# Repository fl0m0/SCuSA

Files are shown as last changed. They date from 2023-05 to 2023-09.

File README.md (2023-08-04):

# SCuSA
 **S**cope **Cu**rrent **S**ense **A**mplifier, work in progress

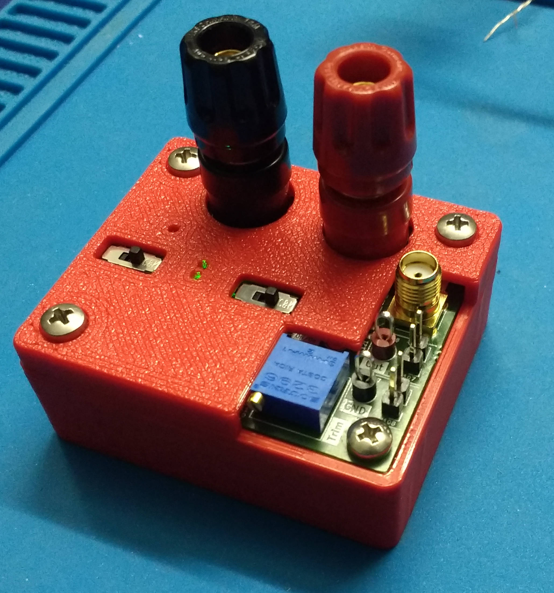
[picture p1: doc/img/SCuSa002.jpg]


# Design goals

The main reason I designed this current sense amplifier was the need to verify power supplys on PCBs:

* Turn on behavior
* Inrush current
* Short circuit current
* Ripple current

My main requirements were:

* High side measurement > 60 V
* Common mode input range down to 0 V
* Burden voltage below 150 mV
* No galvanic isolation
* Current range up to approx ~3 A
* Accuracy better than 2%
* Bandwith > 150 kHz
* Bonus: Measurement of negative current (for battery charging applications)

I had already built a simple current sense amplifier based on the [INA169](https://www.ti.com/product/INA169) on a breadboard. It fullfilled most of my requirements except the common mode voltage range: 2.7 V made it impossible to measure 1.8 V or 1.0 V voltage supplies which are quite common these days.

I ended up with a design way to complicated and expensive :-) But I really wanted to try out a few interesting ICs:

* [LM27762](https://www.ti.com/product/LM27762): "Low-Noise Positive and Negative Output Integrated Charge Pump Plus LDO"
* [AD8210A](https://www.analog.com/en/products/ad8210.html) or [AD8418A](https://www.analog.com/en/products/ad8418a.html): Very fancy looking "High Voltage, Bidirectional Current Shunt Monitors"

# Current status

* RevA built and partially tested
* Documentation not finished
* RevB work in progress (fixed errors, improvements)

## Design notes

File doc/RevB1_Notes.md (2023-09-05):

# Modifications

1. Change F1 to 0.75 A polyfuse SMD1206B075TF/16

2. Bodge wire to U111 charge pump VIN pin. Othervise the output voltage stayed at 1.6 V. This is due to an layout error: EN was mistaken with VIN. The resulting impedance of the long, narrow track to VIN was obviously to high (the switching frequency is 2 MHz!).

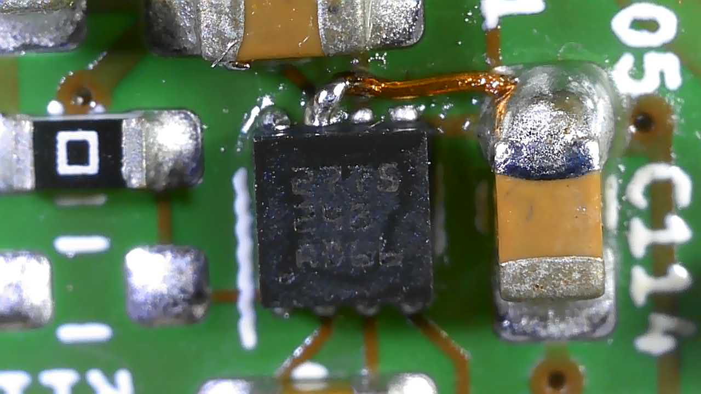
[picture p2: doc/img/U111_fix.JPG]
   

# Power supply

Current consumption is 20 mA. Iq of [LM2775](https://www.ti.com/lit/ds/symlink/lm2775.pdf?ts=1693816107344&ref_url=https%253A%252F%252Fwww.google.com%252F) is 5 mA typ. with forced PWM mode (PFM = 0). Doesn't vary with change of input voltage.

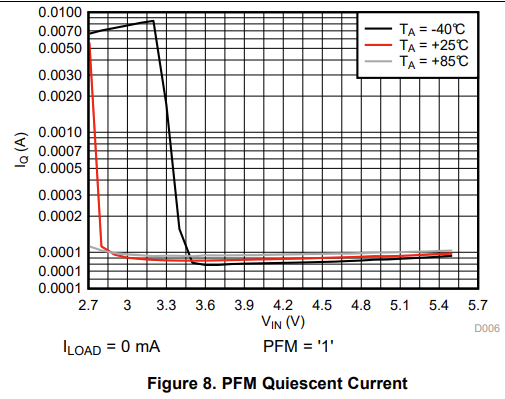
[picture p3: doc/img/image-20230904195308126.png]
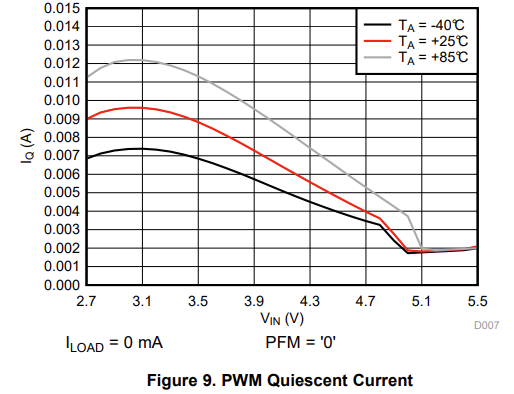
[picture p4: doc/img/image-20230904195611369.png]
 

In RevA1 current consumption was 7 mA with Vx- = GND (-2V unused but present). The "old" LM27762 had an Iq of 390 µA.

| Component | Quiescent Current (mA) |
| --- | --- |
| AD8418A | 4.1 |
| AD8655 | 3.7 |
| LM2775 | 5.0 |
| **Total** | **12.8** |

Efficency is around 45%:

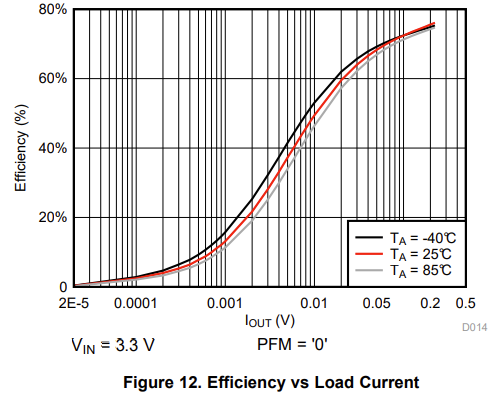
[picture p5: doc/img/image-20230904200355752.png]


$\frac{(4.1\ +\ 3.7)\ mA}{45\ \%}\ =\ 17.3\ mA$ so the measurements seem plausible. PFM mode shouldn't improve the results with load current > 7 mA:

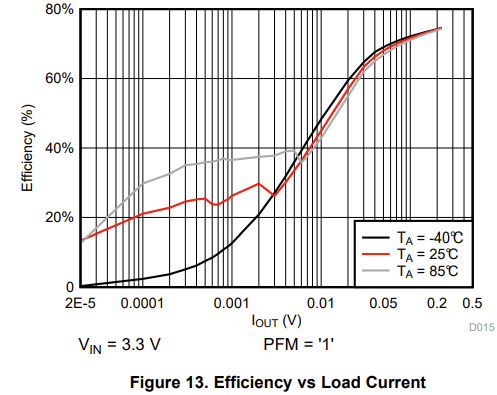
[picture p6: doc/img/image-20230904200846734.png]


## +5V voltage ripple

First screenshot before ferrite, second after ferrite. Filter reduces the ripple approx. 2.7 times.

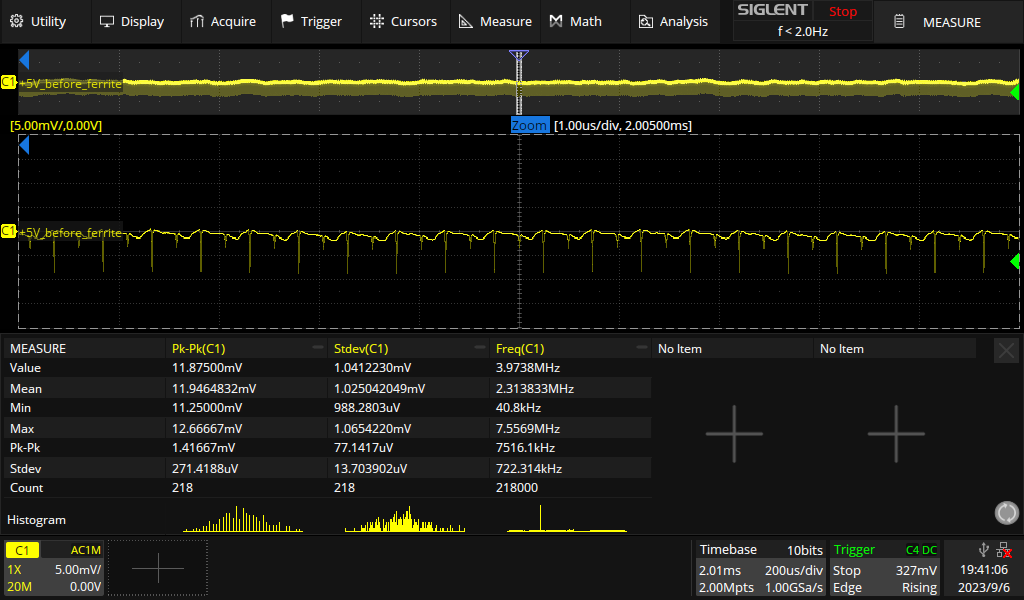
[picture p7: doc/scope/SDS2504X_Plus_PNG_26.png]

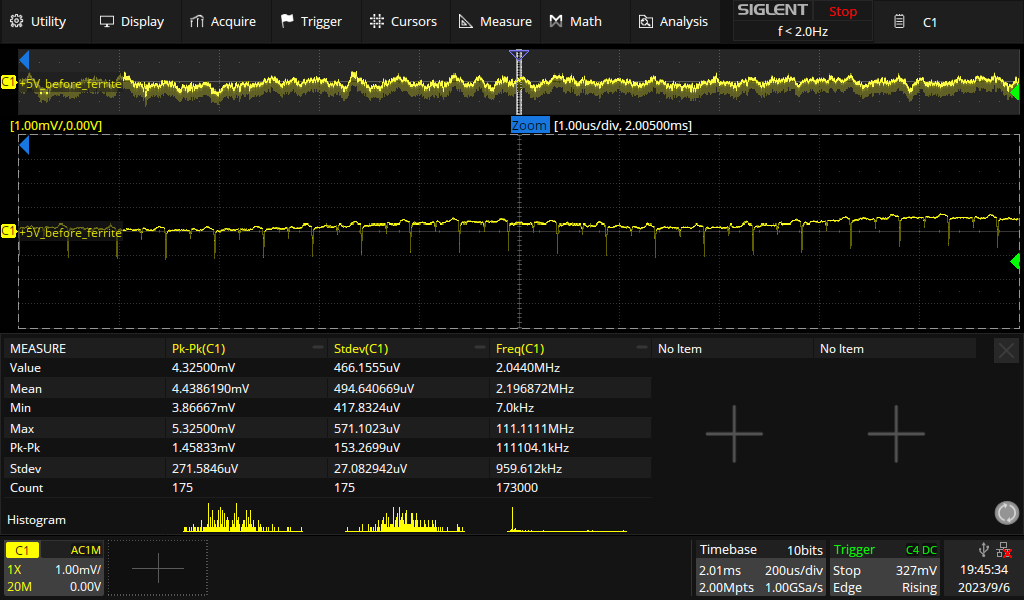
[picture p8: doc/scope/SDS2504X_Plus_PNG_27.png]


+5V after ferrite, bufferd output loaded with 50 Ohms. No significant increase in ripple voltage.

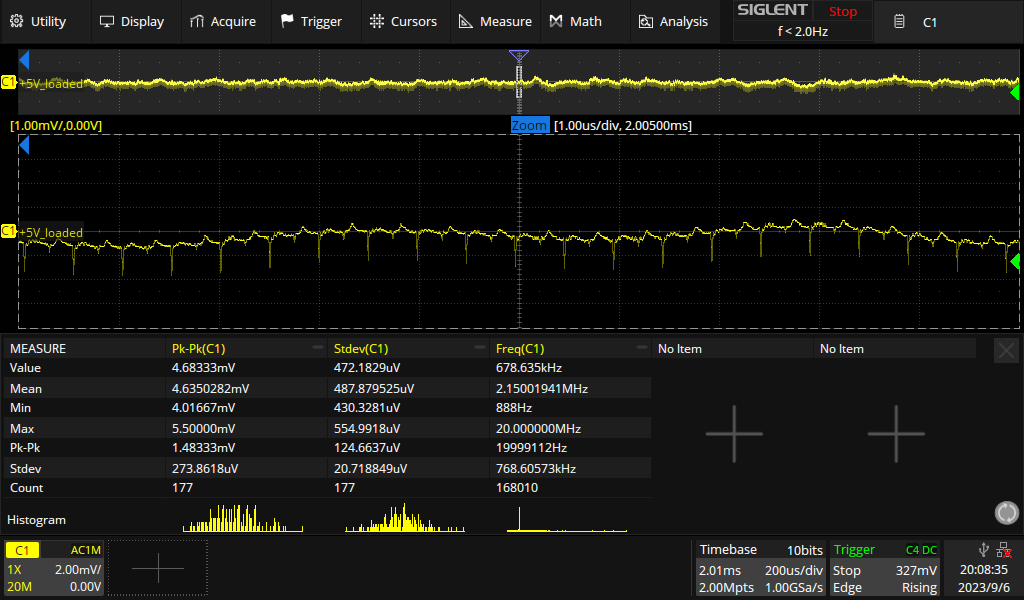
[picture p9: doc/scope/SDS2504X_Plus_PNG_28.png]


## Load regulation

See spreadsheet

# Output measurements

## Output voltage at 0 A

`Probe` = unbuffered output

`Koax` = 50R buffered output

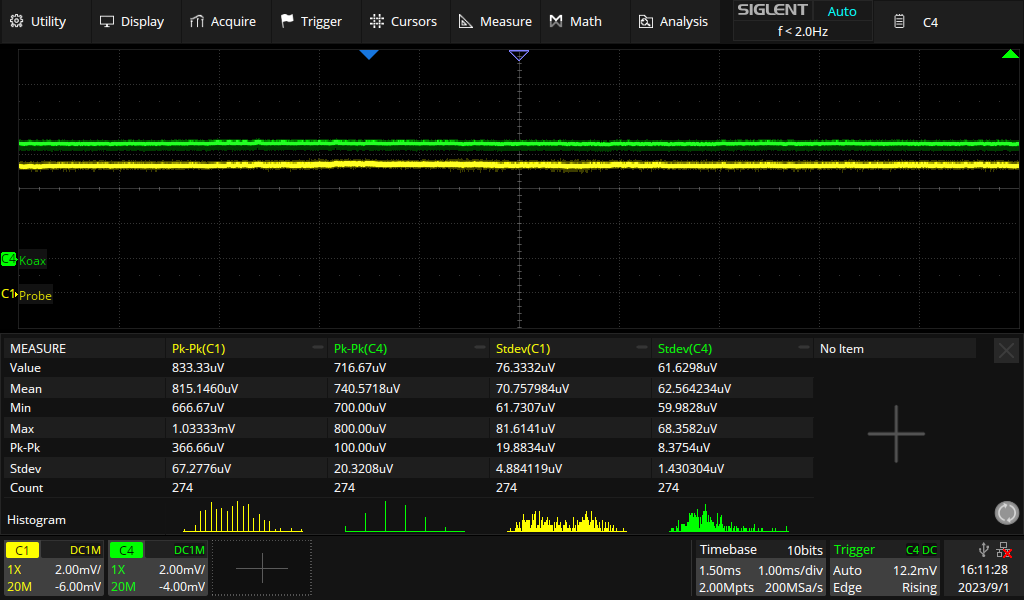
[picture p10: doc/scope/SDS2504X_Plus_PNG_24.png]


## Square wave measurement

Measurement (`C1`) of a 6.6 V, 10 kHz square (`C3 `) wave with 22 Ohms load. 

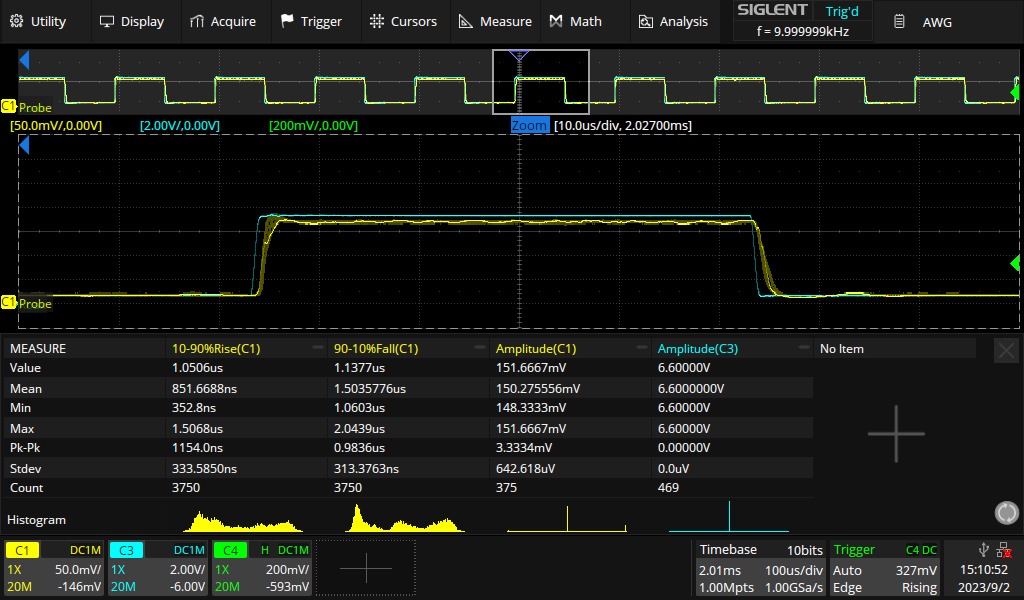
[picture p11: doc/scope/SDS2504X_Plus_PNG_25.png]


# Thermal Images

## Battery Charger

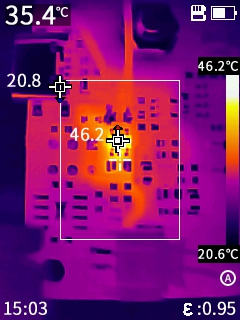
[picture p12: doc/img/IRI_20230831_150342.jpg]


## Sense Resistor

@ 3 A, 5 A, 6 A (6 A not in steady state, temp. still slowly rising). Max. continuous current should be limited to 5 A.

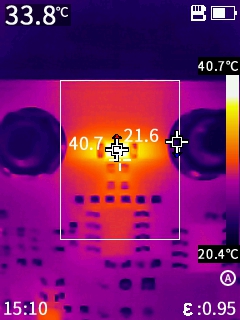
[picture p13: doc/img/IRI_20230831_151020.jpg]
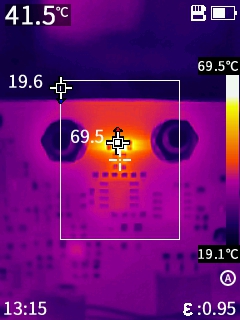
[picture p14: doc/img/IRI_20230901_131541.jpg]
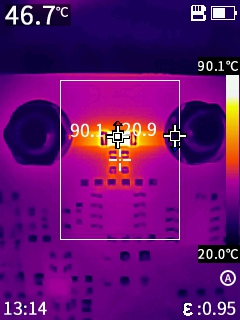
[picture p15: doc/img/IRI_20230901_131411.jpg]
  

## Charge Pump

No Load:

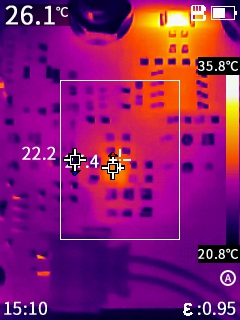
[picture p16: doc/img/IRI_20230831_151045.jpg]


Load 50R max. Vout (4.6 V):

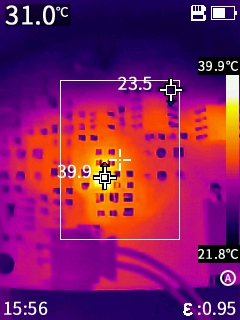
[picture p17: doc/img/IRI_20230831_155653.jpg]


## 50R Output Buffer

With 50R load at max. Vout = 4.6 V. The output voltage swing doesn't reach the full 5 V supply voltage. Without 50R load the output voltage is very close to the supply voltage.

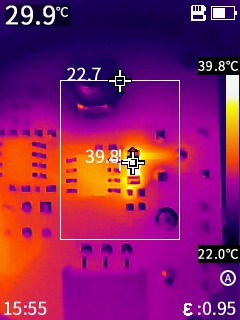
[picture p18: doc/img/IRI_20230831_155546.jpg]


Whole PCB:

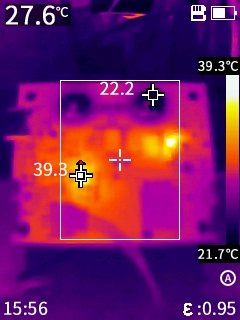
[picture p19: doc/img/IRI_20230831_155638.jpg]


# Changes for RevC1

1. Increase trace width to sense resistor (main current path)
2. Change distance of binding posts to 3/4 inch to support double banana plugs.

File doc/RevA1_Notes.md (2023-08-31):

# Errors

1. C101, C102: wrong footprint, 0805 instead of 0603
2. FB100, FB101: wrong footprint, 1206 instead of 0805 but 742792620 should be 0603
3. DNP parts are shown on ibom
4. U103: wrong pinout (should be non-R type), GND and RESET flipped.

# Modifications

1. FB100, FB101: used 742792118 (had the right footprint and was available as leftover from previous projects)
1. R104 changed to 1.2k to adjust charging indicator LED brightness
1. R103 changed to 4.7k to increase charge current to ~ 210 mA
1. Replace U103 with [BD4836G](https://fscdn.rohm.com/en/products/databook/datasheet/ic/power/voltage_detector/bd48xxg-e.pdf), 3.6 V Supervisor in SOT-23-5 package. Solder bodge wire on pad 3 to pin 2.

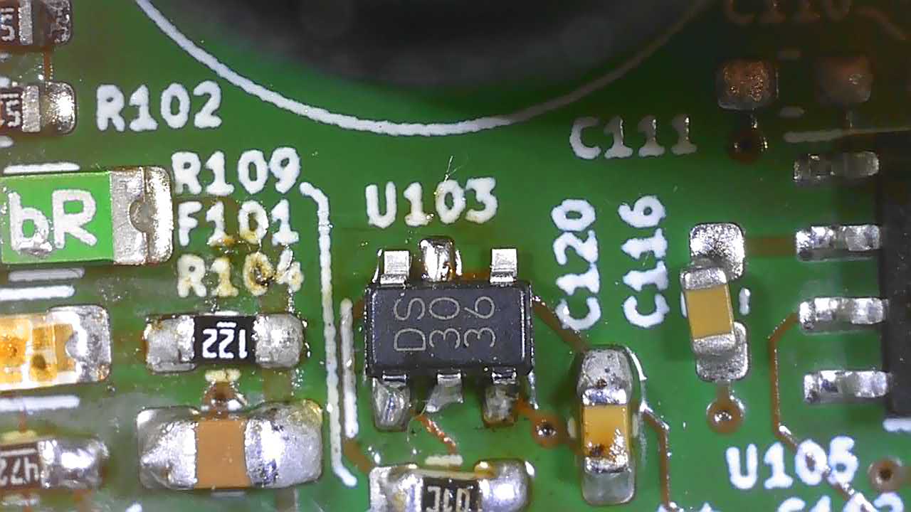
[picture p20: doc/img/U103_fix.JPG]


# To Dos

1. Full charging cycle
2. Use a real USB-Power Supply
3. Negative measure current
4. Solder voltage supervisor
5. Measure current consumption

# Battery

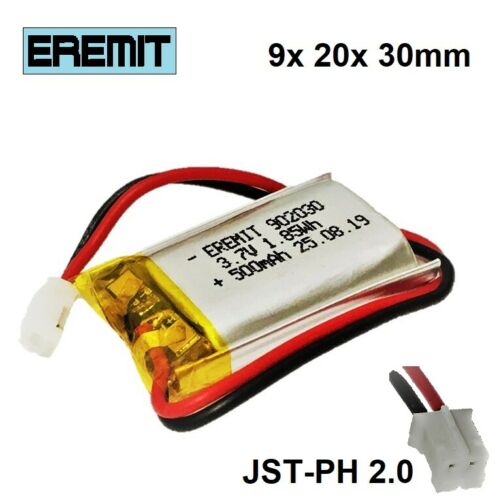
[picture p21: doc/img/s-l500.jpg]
Zertifizierte EREMIT LiPo LiIon Akku Batterie 1S JST-PH 2.0 Stecker GPS Arduino - Bild 6 von 16


* From ebay "Zertifizierte EREMIT LiPo LiIon Akku Batterie 1S JST-PH 2.0 Stecker GPS Arduino"
* Integrated protection circutry: Overchare, overdischarge, overcurrent

| Parameter | Symbol  | Value |
| --- | --- | --- |
| Technology | | Lithium Polymer |
| Dimensions | | 9x 20x 30mm |
| Capacity | C | 500 mAh |
| Nominal charing current  | I_c,nom | 0,5 C |
| Maximum charging current | I_c,max | 1 C |
| Nominal voltage | V_nom | 3.7 V |
| Maximum voltage | V_max | 4.2 V |
| Internal resistance | R_ESR | 90 mR - 120 mR  |

# Photos

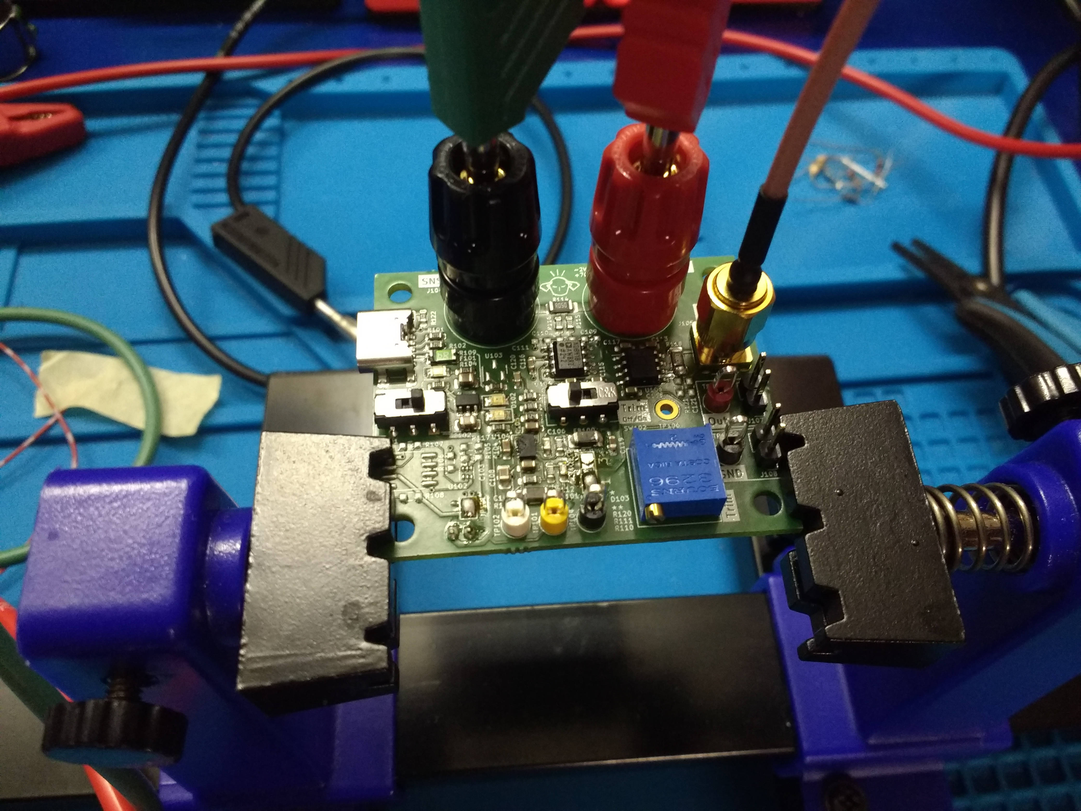
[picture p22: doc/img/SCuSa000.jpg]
 

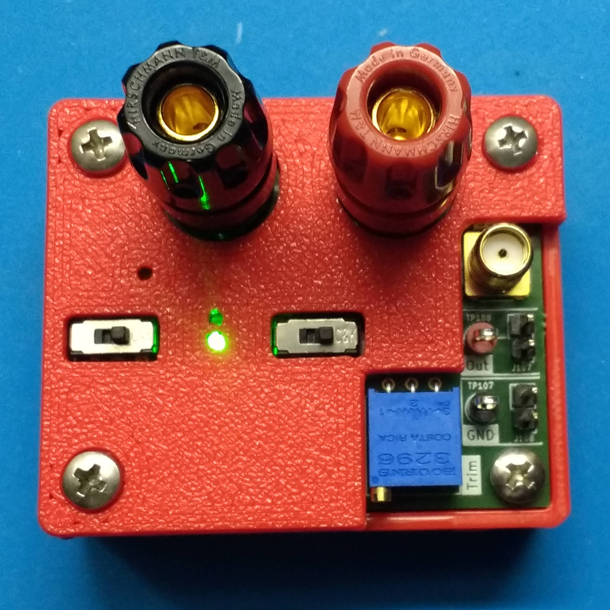
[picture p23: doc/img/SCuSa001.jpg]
 

 

# Measurements

* `PGOOD` LED turns off below 3.14 V

* `Low_Bat` Turns on at 3 V. Expected but to low. Should be 3.5 V or 3.6 V.
* Charging current = 230 mA
* Current consumption = 15,9 mA (without 50R termination connected to the SMA connector)

## Supply rail voltage ripple

+3V3

V_PP = 4,9 mV

V_RMS = 855 µV

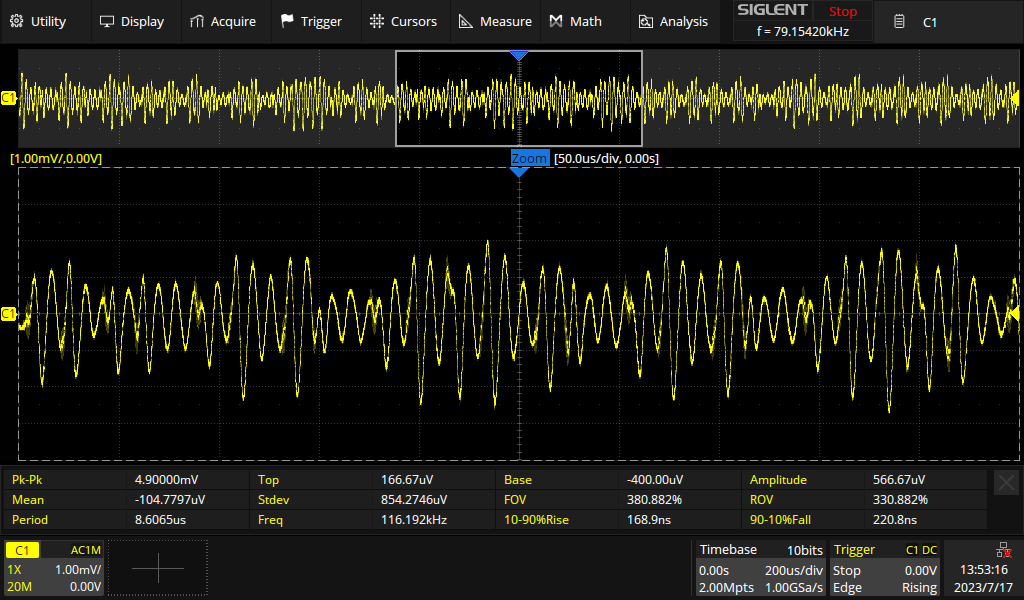
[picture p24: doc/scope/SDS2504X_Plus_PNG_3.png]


+3V3 after ferrite bead:

V_PP = 4,5 mV

V_RMS = 814 µV

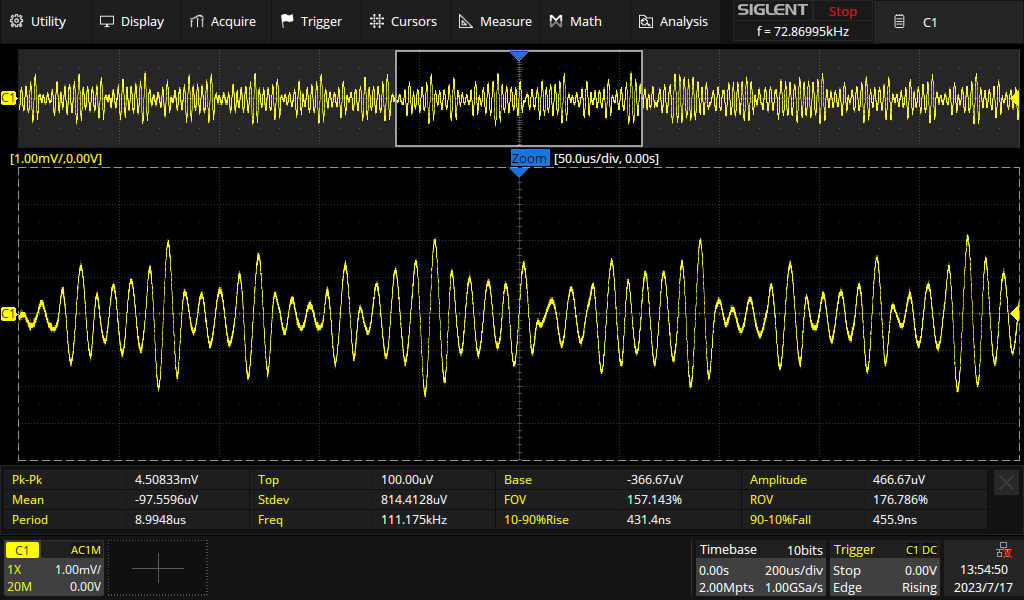
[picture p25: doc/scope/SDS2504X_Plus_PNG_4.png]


-2V:

V_PP = 5,3 mV

V_RMS = 1,1 mV



-2V after ferrite bead:

V_PP = 4,13 mV

V_RMS = 800 µV



# Output signal noise

5mR sense resistor. CH2 set to high impedance input

CH1: Current sense amplifier output

CH2: 50R buffer output (actually 47R, no termination resistor in scope)

V_PP = 12,5 mV

V_RMS = 1,43 mV



## Correlation with power supply ripple

No obvious correlation. Signal noise seems to be inherent to signal chain, not supply voltage.

F1 = FFT(C1), F2 = FFT(C2)





# Accuracy

**Measurement setup:**

* PSU GPP-4323 as power source. Current readings taken from PSU. Accuracy above 50 mA is approx. 1%, below more like 5%.
* DUT directly connected to PSU (constant current, almost short circuit operation)

**Results:**

* 1,5% accuracy approx. from 50 mA to 3 A.



# Frequency Response

## Bode plot

**Measurement setup:**

* Siglent SDS2504X Plus
  * Generator level 3 Vpp (50R)
  * CH1 = DUT voltage output
  * CH2 = Measured generator level
* DUT with 50R in series connected to signal generator (resulting peak to peak current = 3 Vpp / (50R + 50R) = 30 mA)

**Results:**

* 3dB bandwidth = 232 kHz

* Output voltage amplitude in Vpp:

 

* CH1 / CH2 in dB (why -34dB? Current sense amplifier is scaling 1 A / 1 V. With 100 R the current is 100 times smaller than the generator voltage. 1/100 = -40dB. The difference of 6dB = 0,5 comes from the voltage divider: generator output resistance and the resistance added to the current path. Both are 50R)

 

## Time domain (square wave)

Same measurement setup as in [Bode plot](#Bode plot). The noise is relatively high because of the limited current capability of the signal generator (this applies for the bode plot, too).

 
 
 

# Change to single supply

With JP103 in setting 2-3 the negative supply voltage is set to GND. I implemented this option to because I wasn't sure if a dual supply is such a good idea. **It was not!**



V_PP drops from 12.5 mV to 2.5 mV, V_RMS drops from 1.43 mV to 180 µV at the current sense amplifier output. The noise at the 50R buffer (CH4) is even lower.

I guess this is where the Power Supply Rejection Ratio (PSRR) of the amplifier comes into play. With a dual supply and the scope measurement referenced to ground the PSRR doesn't do anything. For a redesign I will use a step up converter and a single supply. Possible parts:

* [LM2750](https://www.ti.com/lit/ds/symlink/lm2750.pdf) or [LM2775](https://www.ti.com/lit/ds/symlink/lm2775.pdf)
* [NCP163](https://www.onsemi.com/download/data-sheet/pdf/ncp163-d.pdf) as post regulator, fixed voltage of 4.5V
* [TPS7A49](https://www.ti.com/lit/ds/symlink/tps7a49.pdf) as post regulator, adjustable voltage, ~300 mV dropout, high PSRR > 1 MHz



# Notes

* Trimming potentiometer can be used to increase the positive (or negative) measurement range. Turing it fully left offsets the output voltage to -2 V. This increases the positive current measurement range to 5.3 A (3.3 V - (-2 V)).

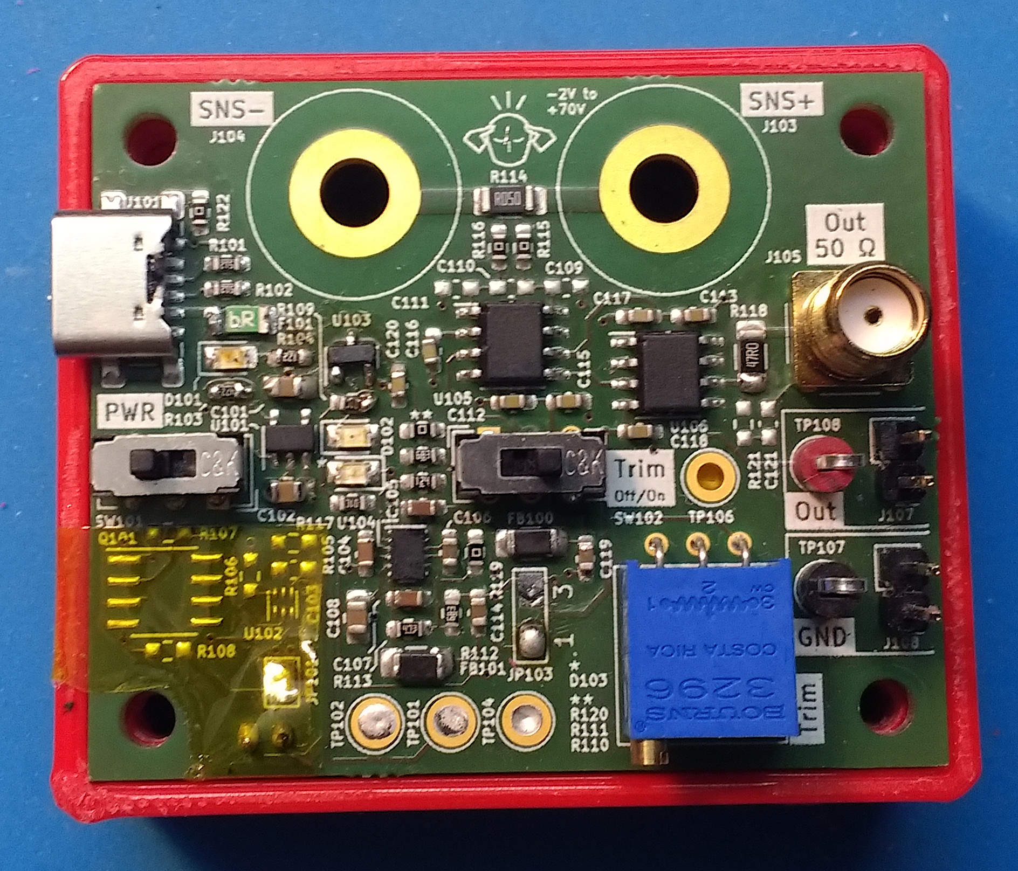
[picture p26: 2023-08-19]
doc/img/top00.jpg

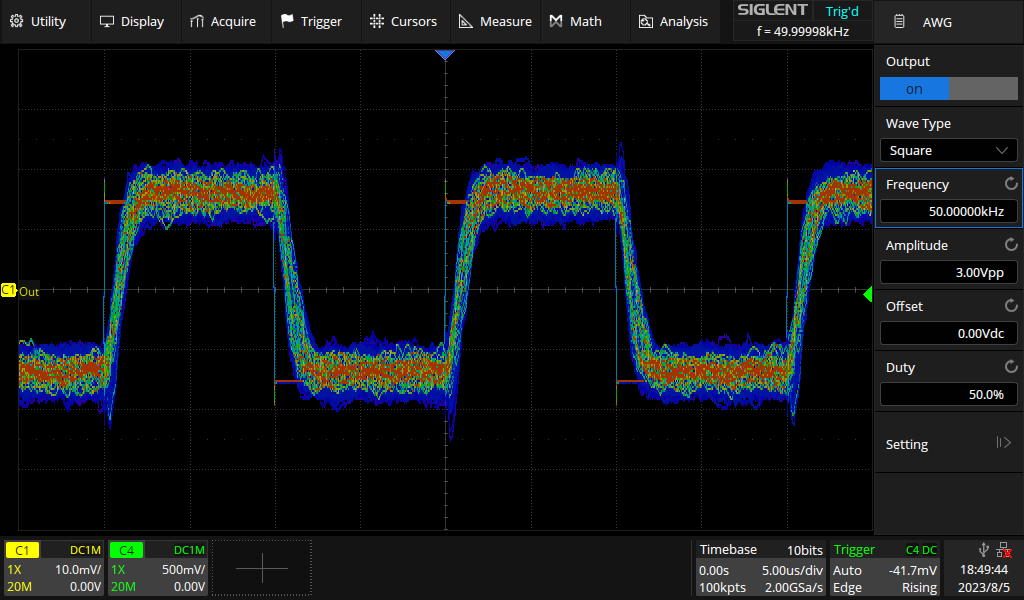
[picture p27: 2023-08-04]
doc/scope/SDS2504X_Plus_PNG_18.png

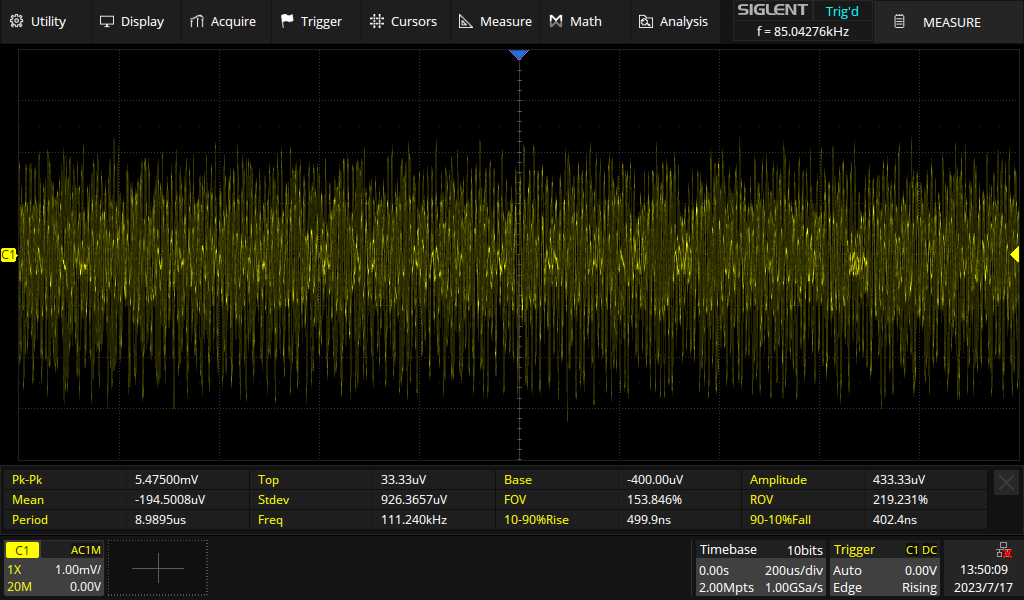
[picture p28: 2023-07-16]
doc/scope/SDS2504X_Plus_PNG_2.png

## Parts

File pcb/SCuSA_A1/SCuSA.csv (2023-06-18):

Source: | C:\Users\Florian\Documents\GitHub\SCuSA\pcb\SCuSA_A1\SCuSA.kicad_sch
Date: | 6/11/2023 1:48:05 PM
Tool: | Eeschema 7.0.5
Generator: | C:\Program Files\KiCad\7.0\bin\scripting\plugins/bom_csv_grouped_by_value.py
Component Count: | 70
Collated Components:
Item | Qty | Reference(s) | Value | LibPart | Footprint | Datasheet | DNP | Color | Info | MPN | Manufacturer | Package | Power | Pretty Value 1 | Pretty Value 2 | Resistance | SPN | Supplier | Tolerance
1 | 4 | C101, C102, C106, C114 | 1uF,16V,X7R,0603 | Capacitor_User:1uF,16V,X7R,0603 | Capacitor_SMD:C_0603_1608Metric_Pad1.08x0.95mm_HandSolder | ~ |  |  |  |  |  |  |  | 1μF, 16V | X7R, 0603
2 | 3 | C103, C112, C113 | 100nF,16V,X7R,0603 | Capacitor_User:100nF,16V,X7R,0603 | Capacitor_SMD:C_0603_1608Metric_Pad1.08x0.95mm_HandSolder | ~ |  |  |  |  |  |  |  | 100nF, 16V | X7R, 0603
3 | 3 | C104, C105, C107 | 2.2uF,25V,X7R,0603 | Capacitor_User:2.2uF,25V,X7R,0603 | Capacitor_SMD:C_0603_1608Metric_Pad1.08x0.95mm_HandSolder | ~ |  |  |  |  |  |  |  | 2.2μF, 25V | X7R, 0603
4 | 1 | C108 | 4.7uF,25V,X7R,0805 | Capacitor_User:4.7uF,25V,X7R,0805 | Capacitor_SMD:C_0805_2012Metric_Pad1.18x1.45mm_HandSolder | ~ |  |  |  |  |  |  |  | 4.7μF, 25V | X7R, 0805
5 | 3 | C109, C110, C111 | 100nF,100V,X7R,0603 | Capacitor_User:100nF,100V,X7R,0603 | Capacitor_SMD:C_0603_1608Metric_Pad1.08x0.95mm_HandSolder | ~ | DNP |  |  |  |  |  |  | 100nF, 100V | X7R, 0603
6 | 1 | D101 | 150080BS75000 | LED_User:150080BS75000 | LED_SMD:LED_0805_2012Metric_Pad1.15x1.40mm_HandSolder | https://www.we-online.com/katalog/datasheet/150080BS75000.pdf |  |  | Blue |  | Wurth Elektronik |  |  |  |  |  | 732-4982-1-ND | Digi-Key
7 | 1 | D102 | 150080SS75000 | LED_User:150080SS75000 | LED_SMD:LED_0805_2012Metric_Pad1.15x1.40mm_HandSolder | https://www.we-online.com/katalog/datasheet/150080SS75000.pdf |  |  | Red |  | Wurth Elektronik |  |  |  |  |  | 732-4985-1-ND | Digi-Key
8 | 1 | D103 | 150080GS75000 | LED_User:150080GS75000 | LED_SMD:LED_0805_2012Metric_Pad1.15x1.40mm_HandSolder | https://www.we-online.com/katalog/datasheet/150080GS75000.pdf |  |  | Green |  | Wurth Elektronik |  |  |  |  |  | 732-4983-1-ND | Digi-Key
9 | 1 | F101 | 0ZCJ0110FF2E | Fuse_User:0ZCJ0110FF2E | Fuse:Fuse_1206_3216Metric_Pad1.42x1.75mm_HandSolder | https://www.belfuse.com/resources/datasheets/circuitprotection/ds-cp-0zch-series.pdf |  |  | 1.1 A, 8V | 0ZCJ0110FF2E | Bel Fuse |  |  |  |  |  | 507-1807-1-ND | Digi-Key
10 | 1 | FB101 | 742792620 | Ferrite_User:742792620 | Inductor_SMD:L_1206_3216Metric_Pad1.42x1.75mm_HandSolder | https://www.we-online.com/components/products/datasheet/742792620.pdf |  |  | 100Ω, 0.5A | 742792620 | Wurth Electronics |  |  |  |  |  | 732-1579-1-ND | Digi-Key
11 | 4 | H101, H102, H103, H104 | MountingHole | Mechanical:MountingHole | MountingHole:MountingHole_3.2mm_M3_DIN965 | ~
12 | 1 | J101 | USB4135-GF-A | Connector_User:USB4135-GF-A | Connector_User:USB-C_Receptacle_GTC_USB4135-GF-A | https://gct.co/de-de/connector/usb4135 |  |  |  | USB4135-GF-A | GTC |  |  |  |  |  | 2073-USB4135-GF-ACT-ND | Digi-Key
13 | 1 | J102 | JST_S2B-PH-K-x | :JST_S2B-PH-K-x_1 | Connector_JST:JST_PH_S2B-PH-K_1x02_P2.00mm_Horizontal | https://www.jst-mfg.com/product/pdf/eng/ePH.pdf |  |  |  | S2B-PH-K-S | JST |  |  |  |  |  | 455-1719-ND | Digi-Key
14 | 1 | J103 | Binding_Post_PK4_Red | Connector_User:Binding_Post_PK4_Red | Connector_User:Binding_Post_PK4_Red | https://cdn-reichelt.de/documents/datenblatt/C170/DS_PK4_1.pdf |  |  |  |  |  |  |  |  |  |  | PK 4 RT | Reichelt
15 | 1 | J104 | Binding_Post_PK4_Black | Connector_User:Binding_Post_PK4_Black | Connector_User:Binding_Post_PK4_Black | https://cdn-reichelt.de/documents/datenblatt/C170/DS_PK4_1.pdf |  |  |  |  |  |  |  |  |  |  | PK 4 SW | Reichelt
16 | 1 | J105 | SMA_Straight_Jack_Female | Connector_User:SMA_Straight_Jack_Female | Connector_User:SMA_Vertical | https://app.adam-tech.com/products/download/data_sheet/219105/rf2-04a-t-00-50-g-data-sheet.pdf |  |  |  | RF2-04A-T-00-50-G | Adam Tech |  |  |  |  |  | 2057-RF2-04A-T-00-50-G-ND | Digi-Key
17 | 2 | J107, J108 | 77311-118-02LF | Connector_User:77311-118-02LF | Connector_PinHeader_2.54mm:PinHeader_1x02_P2.54mm_Vertical | https://cdn.amphenol-icc.com/media/wysiwyg/files/drawing/77311.pdf |  |  |  |  | Amphenol |  |  |  |  |  | 609-4434-ND | Digi-Key
18 | 1 | JP101 | SolderJumper_2_Open | Jumper:SolderJumper_2_Open | Jumper:SolderJumper-2_P1.3mm_Open_TrianglePad1.0x1.5mm | ~
19 | 1 | JP103 | SolderJumper_3_Bridged12 | Jumper:SolderJumper_3_Bridged12 | Jumper:SolderJumper-3_P1.3mm_Bridged12_Pad1.0x1.5mm_NumberLabels | ~
20 | 1 | Q101 | DMN2041LSD | Transistor_FET_User:DMN2041LSD | Package_SO:SOIC-8_3.9x4.9mm_P1.27mm | https://www.diodes.com/assets/Datasheets/ds31964.pdf |  |  |  | DMN2041LSD-13 | Diodes Incorporated |  |  |  |  |  | DMN2041LSD-13DICT-ND | Digi-Key
21 | 2 | R101, R102 | 5.1k,0603 | Resistor_User:5.1k,0603 | Resistor_SMD:R_0603_1608Metric_Pad0.98x0.95mm_HandSolder | ~ |  |  |  |  |  | 0603 | 0.1W |  |  | 5.1k |  |  | 1%
22 | 3 | R103, R109, R117 | 10k,0603 | Resistor_User:10k,0603 | Resistor_SMD:R_0603_1608Metric_Pad0.98x0.95mm_HandSolder | ~ |  |  |  |  |  | 0603 | 0.1W |  |  | 10k |  |  | 1%
23 | 1 | R104 | 470R,0603 | Resistor_User:470R,0603 | Resistor_SMD:R_0603_1608Metric_Pad0.98x0.95mm_HandSolder | ~ |  |  |  |  |  | 0603 | 0.1W |  |  | 470R |  |  | 1%
24 | 1 | R105 | 330R,0603 | Resistor_User:330R,0603 | Resistor_SMD:R_0603_1608Metric_Pad0.98x0.95mm_HandSolder | ~ |  |  |  |  |  | 0603 | 0.1W |  |  | 330R |  |  | 1%
25 | 1 | R106 | 2.2k,0603 | Resistor_User:2.2k,0603 | Resistor_SMD:R_0603_1608Metric_Pad0.98x0.95mm_HandSolder | ~ |  |  |  |  |  | 0603 | 0.1W |  |  | 2.2k |  |  | 1%
26 | 2 | R107, R108 | 5.1M,0603 | Resistor_User:5.1M,0603 | Resistor_SMD:R_0603_1608Metric_Pad0.98x0.95mm_HandSolder | ~ |  |  |  |  |  | 0603 | 0.1W |  |  | 5.1M |  |  | 1%
27 | 1 | R110 | 120k,0603 | Resistor_User:120k,0603 | Resistor_SMD:R_0603_1608Metric_Pad0.98x0.95mm_HandSolder | ~ |  |  |  |  |  | 0603 | 0.1W |  |  | 120k |  |  | 1%
28 | 2 | R111, R112 | 68k,0603 | Resistor_User:68k,0603 | Resistor_SMD:R_0603_1608Metric_Pad0.98x0.95mm_HandSolder | ~ |  |  |  |  |  | 0603 | 0.1W |  |  | 68k |  |  | 1%
29 | 1 | R113 | 47k,0603 | Resistor_User:47k,0603 | Resistor_SMD:R_0603_1608Metric_Pad0.98x0.95mm_HandSolder | ~ |  |  |  |  |  | 0603 | 0.1W |  |  | 47k |  |  | 1%
30 | 1 | R114 | 50m | Resistor_User:50m,1206 | Resistor_SMD:R_1206_3216Metric_Pad1.30x1.75mm_HandSolder | ~ |  |  |  |  |  | 1206 | 1W |  |  | 50m |  |  | 0.5%
31 | 4 | R115, R116, R119, R120 | 0R,0603 | Resistor_User:0R,0603 | Resistor_SMD:R_0603_1608Metric_Pad0.98x0.95mm_HandSolder | ~ |  |  |  |  |  | 0603 | 0.1W |  |  | 0R |  |  | 1%
32 | 1 | R118 | 49.9R,1206 | Resistor_User:49.9R,1206 | Resistor_SMD:R_1206_3216Metric_Pad1.30x1.75mm_HandSolder | ~ |  |  |  |  |  | 1206 | 0.5W |  |  | 49.9R |  |  | 1%
33 | 1 | RV101 | 10k_Potentiometer_Trim_TSR-3296W | Resistor_User:10k_Potentiometer_Trim_TSR-3296W | Potentionmeter_THT_User:Potentiometer_Suntan_3296W_Vertical_90deg | https://cdn-reichelt.de/documents/datenblatt/B400/64W100K.pdf |  |  |  | TSR-3296W | Suntan |  |  |  |  |  | 64W-10K | Reichelt
34 | 2 | SW101, SW102 | JS202011CQN | Switch_User:Slide_Switch_JS202011CQN | Button_Switch_THT:SW_CuK_JS202011CQN_DPDT_Straight | https://www.ckswitches.com/media/1422/js.pdf |  |  |  | JS202011CQN | CuK |  |  |  |  |  | 401-2001-ND | Digi-Key
35 | 4 | TP101, TP103, TP105, TP108 | TestPoint_5010_Red | Testpoint_User:TestPoint_5010_Red | TestPoint:TestPoint_Loop_D2.60mm_Drill1.6mm_Beaded | https://www.keystone-europe.com/wp-content/uploads/2019/11/M70_keystone_guide_2019.pdf |  | Red |  | 5010 | Keystone Electronics |  |  |  |  |  | 36-5005-ND | Digi-Key
36 | 3 | TP102, TP104, TP107 | TestPoint_5011_Black | Testpoint_User:TestPoint_5011_Black | TestPoint:TestPoint_Loop_D2.60mm_Drill1.6mm_Beaded | https://www.keystone-europe.com/wp-content/uploads/2019/11/M70_keystone_guide_2019.pdf |  | Black |  | 5011 | Keystone Electronics |  |  |  |  |  | 36-5011-ND | Digi-Key
37 | 1 | TP106 | TestPoint_5012_White | Testpoint_User:TestPoint_5012_White | TestPoint:TestPoint_Loop_D2.60mm_Drill1.6mm_Beaded | https://www.keystone-europe.com/wp-content/uploads/2019/11/M70_keystone_guide_2019.pdf |  | White |  | 5012 | Keystone Electronics |  |  |  |  |  | 36-5012-ND | Digi-Key
38 | 1 | U101 | MCP73832T-2ACI/OT | Battery_Management:MCP73832-2-OT | Package_TO_SOT_SMD:SOT-23-5 | http://ww1.microchip.com/downloads/en/DeviceDoc/20001984g.pdf |  |  |  |  |  |  |  |  |  |  | MCP73832T-2ACI/OTCT-ND | Digi-Key
39 | 1 | U102 | BQ29700DSER | Battery_Management:BQ297xy | Package_SON:WSON-6_1.5x1.5mm_P0.5mm | http://www.ti.com/lit/ds/symlink/bq2970.pdf
40 | 1 | U103 | TLV803EA30DBZR | Power_Supervisor_User:TLV803EA30DBZR | Package_TO_SOT_SMD:SOT-23 | https://www.ti.com/lit/ds/symlink/tlv803e.pdf |  |  |  | TLV803EA30DBZR | Texas Instruments |  |  |  |  |  | 296-TLV803EA30DBZRCT-ND | Digi-Key
41 | 1 | U104 | LM27762 | Regulator_SwitchedCapacitor:LM27762 | Package_SON:WSON-12-1EP_3x2mm_P0.5mm_EP1x2.65_ThermalVias | http://www.ti.com/lit/ds/symlink/lm27762.pdf |  |  |  |  |  |  |  |  |  |  | 296-47331-1-ND | Digi-Key
42 | 1 | U105 | AD8410AWBRZ | Amplifier_Current:AD8418 | Package_SO:SOIC-8_3.9x4.9mm_P1.27mm | https://www.analog.com/media/en/technical-documentation/data-sheets/AD8418.pdf |  |  |  |  |  |  |  |  |  |  | 505-AD8410AWBRZ-ND | Digi-Key
43 | 1 | U106 | AD8655ARZ | Amplifier_Operational:AD8655 | Package_SO:SOIC-8_3.9x4.9mm_P1.27mm | https://www.analog.com/media/en/technical-documentation/data-sheets/ad8655_8656.pdf |  |  |  |  |  |  |  |  |  |  | 505-AD8655ARZ-ND | Digi-Key

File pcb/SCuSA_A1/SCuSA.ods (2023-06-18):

 |  |  | Source: | C:\Users\Florian\Documents\GitHub\SCuSA\pcb\SCuSA_A1\SCuSA.kicad_sch
 |  |  | Date: | 6/11/2023 1:48:05 PM
 |  |  | Tool: | Eeschema 7.0.5
 |  |  | Generator: | C:\Program Files\KiCad\7.0\bin\scripting\plugins/bom_csv_grouped_by_value.py
 |  |  | Component Count: | 70
 |  |  | Collated Components:
Vorhanden | Bestellt | Händler | Item | Qty | Reference(s) | Value | LibPart | Footprint | Datasheet | DNP | Color | Info | MPN | Manufacturer | Package | Power | Pretty Value 1 | Pretty Value 2 | Resistance | SPN | Supplier | Tolerance
Ja |  |  | 1 | 4 | C101, C102, C106, C114 | 1uF,16V,X7R,0603 | Capacitor_User:1uF,16V,X7R,0603 | Capacitor_SMD:C_0603_1608Metric_Pad1.08x0.95mm_HandSolder | ~ |  |  |  |  |  |  |  | 1μF, 16V | X7R, 0603
Ja |  |  | 2 | 3 | C103, C112, C113 | 100nF,16V,X7R,0603 | Capacitor_User:100nF,16V,X7R,0603 | Capacitor_SMD:C_0603_1608Metric_Pad1.08x0.95mm_HandSolder | ~ |  |  |  |  |  |  |  | 100nF, 16V | X7R, 0603
Ja |  |  | 3 | 3 | C104, C105, C107 | 2.2uF,25V,X7R,0603 | Capacitor_User:2.2uF,25V,X7R,0603 | Capacitor_SMD:C_0603_1608Metric_Pad1.08x0.95mm_HandSolder | ~ |  |  |  |  |  |  |  | 2.2μF, 25V | X7R, 0603
Ja | Ja | Digi-Key | 4 | 1 | C108 | 4.7uF,25V,X7R,0805 | Capacitor_User:4.7uF,25V,X7R,0805 | Capacitor_SMD:C_0805_2012Metric_Pad1.18x1.45mm_HandSolder | ~ |  |  |  |  |  |  |  | 4.7μF, 25V | X7R, 0805
Ja |  |  | 5 | 3 | C109, C110, C111 | 100nF,100V,X7R,0603 | Capacitor_User:100nF,100V,X7R,0603 | Capacitor_SMD:C_0603_1608Metric_Pad1.08x0.95mm_HandSolder | ~ | DNP |  |  |  |  |  |  | 100nF, 100V | X7R, 0603
Ja |  |  | 6 | 1 | D101 | 150080BS75000 | LED_User:150080BS75000 | LED_SMD:LED_0805_2012Metric_Pad1.15x1.40mm_HandSolder | https://www.we-online.com/katalog/datasheet/150080BS75000.pdf |  |  | Blue |  | Wurth Elektronik |  |  |  |  |  | 732-4982-1-ND | Digi-Key
Ja |  |  | 7 | 1 | D102 | 150080SS75000 | LED_User:150080SS75000 | LED_SMD:LED_0805_2012Metric_Pad1.15x1.40mm_HandSolder | https://www.we-online.com/katalog/datasheet/150080SS75000.pdf |  |  | Red |  | Wurth Elektronik |  |  |  |  |  | 732-4985-1-ND | Digi-Key
Ja |  | Digi-Key | 8 | 1 | D103 | 150080GS75000 | LED_User:150080GS75000 | LED_SMD:LED_0805_2012Metric_Pad1.15x1.40mm_HandSolder | https://www.we-online.com/katalog/datasheet/150080GS75000.pdf |  |  | Green |  | Wurth Elektronik |  |  |  |  |  | 732-4983-1-ND | Digi-Key
 |  | Digi-Key | 9 | 1 | F101 | 0ZCJ0110FF2E | Fuse_User:0ZCJ0110FF2E | Fuse:Fuse_1206_3216Metric_Pad1.42x1.75mm_HandSolder | https://www.belfuse.com/resources/datasheets/circuitprotection/ds-cp-0zch-series.pdf |  |  | 1.1 A, 8V | 0ZCJ0110FF2E | Bel Fuse |  |  |  |  |  | 507-1807-1-ND | Digi-Key
 |  | Digi-Key | 10 | 1 | FB101 | 742792620 | Ferrite_User:742792620 | Inductor_SMD:L_1206_3216Metric_Pad1.42x1.75mm_HandSolder | https://www.we-online.com/components/products/datasheet/742792620.pdf |  |  | 100Ω, 0.5A | 742792620 | Wurth Electronics |  |  |  |  |  | 732-1579-1-ND | Digi-Key
- | - | - | 11 | 4 | H101, H102, H103, H104 | MountingHole | Mechanical:MountingHole | MountingHole:MountingHole_3.2mm_M3_DIN965 | ~
Ja | - | - | 12 | 1 | J101 | USB4135-GF-A | Connector_User:USB4135-GF-A | Connector_User:USB-C_Receptacle_GTC_USB4135-GF-A | https://gct.co/de-de/connector/usb4135 |  |  |  | USB4135-GF-A | GTC |  |  |  |  |  | 2073-USB4135-GF-ACT-ND | Digi-Key
 |  | Digi-Key | 13 | 1 | J102 | JST_S2B-PH-K-x | :JST_S2B-PH-K-x_1 | Connector_JST:JST_PH_S2B-PH-K_1x02_P2.00mm_Horizontal | https://www.jst-mfg.com/product/pdf/eng/ePH.pdf |  |  |  | S2B-PH-K-S | JST |  |  |  |  |  | 455-1719-ND | Digi-Key
 |  |  | 14 | 1 | J103 | Binding_Post_PK4_Red | Connector_User:Binding_Post_PK4_Red | Connector_User:Binding_Post_PK4_Red | https://cdn-reichelt.de/documents/datenblatt/C170/DS_PK4_1.pdf |  |  |  |  |  |  |  |  |  |  | PK 4 RT | Reichelt
 |  |  | 15 | 1 | J104 | Binding_Post_PK4_Black | Connector_User:Binding_Post_PK4_Black | Connector_User:Binding_Post_PK4_Black | https://cdn-reichelt.de/documents/datenblatt/C170/DS_PK4_1.pdf |  |  |  |  |  |  |  |  |  |  | PK 4 SW | Reichelt
 |  | Digi-Key | 16 | 1 | J105 | SMA_Straight_Jack_Female | Connector_User:SMA_Straight_Jack_Female | Connector_User:SMA_Vertical | https://app.adam-tech.com/products/download/data_sheet/219105/rf2-04a-t-00-50-g-data-sheet.pdf |  |  |  | RF2-04A-T-00-50-G | Adam Tech |  |  |  |  |  | 2057-RF2-04A-T-00-50-G-ND | Digi-Key
Ja |  |  | 17 | 2 | J107, J108 | 77311-118-02LF | Connector_User:77311-118-02LF | Connector_PinHeader_2.54mm:PinHeader_1x02_P2.54mm_Vertical | https://cdn.amphenol-icc.com/media/wysiwyg/files/drawing/77311.pdf |  |  |  |  | Amphenol |  |  |  |  |  | 609-4434-ND | Digi-Key
- | - | - | 18 | 1 | JP101 | SolderJumper_2_Open | Jumper:SolderJumper_2_Open | Jumper:SolderJumper-2_P1.3mm_Open_TrianglePad1.0x1.5mm | ~
- | - | - | 19 | 1 | JP103 | SolderJumper_3_Bridged12 | Jumper:SolderJumper_3_Bridged12 | Jumper:SolderJumper-3_P1.3mm_Bridged12_Pad1.0x1.5mm_NumberLabels | ~
 |  | Digi-Key | 20 | 1 | Q101 | DMN2041LSD | Transistor_FET_User:DMN2041LSD | Package_SO:SOIC-8_3.9x4.9mm_P1.27mm | https://www.diodes.com/assets/Datasheets/ds31964.pdf |  |  |  | DMN2041LSD-13 | Diodes Incorporated |  |  |  |  |  | DMN2041LSD-13DICT-ND | Digi-Key
Ja |  |  | 21 | 2 | R101, R102 | 5.1k,0603 | Resistor_User:5.1k,0603 | Resistor_SMD:R_0603_1608Metric_Pad0.98x0.95mm_HandSolder | ~ |  |  |  |  |  | 603 | 0.1W |  |  | 5.1k |  |  | 1%
Ja |  |  | 22 | 3 | R103, R109, R117 | 10k,0603 | Resistor_User:10k,0603 | Resistor_SMD:R_0603_1608Metric_Pad0.98x0.95mm_HandSolder | ~ |  |  |  |  |  | 603 | 0.1W |  |  | 10k |  |  | 1%
Ja |  |  | 23 | 1 | R104 | 470R,0603 | Resistor_User:470R,0603 | Resistor_SMD:R_0603_1608Metric_Pad0.98x0.95mm_HandSolder | ~ |  |  |  |  |  | 603 | 0.1W |  |  | 470R |  |  | 1%
Ja |  |  | 24 | 1 | R105 | 330R,0603 | Resistor_User:330R,0603 | Resistor_SMD:R_0603_1608Metric_Pad0.98x0.95mm_HandSolder | ~ |  |  |  |  |  | 603 | 0.1W |  |  | 330R |  |  | 1%
Ja |  |  | 25 | 1 | R106 | 2.2k,0603 | Resistor_User:2.2k,0603 | Resistor_SMD:R_0603_1608Metric_Pad0.98x0.95mm_HandSolder | ~ |  |  |  |  |  | 603 | 0.1W |  |  | 2.2k |  |  | 1%
 |  | Digi-Key | 26 | 2 | R107, R108 | 5.1M,0603 | Resistor_User:5.1M,0603 | Resistor_SMD:R_0603_1608Metric_Pad0.98x0.95mm_HandSolder | ~ |  |  |  |  |  | 603 | 0.1W |  |  | 5.1M |  |  | 1%
Ja |  |  | 27 | 1 | R110 | 120k,0603 | Resistor_User:120k,0603 | Resistor_SMD:R_0603_1608Metric_Pad0.98x0.95mm_HandSolder | ~ |  |  |  |  |  | 603 | 0.1W |  |  | 120k |  |  | 1%
Ja |  |  | 28 | 2 | R111, R112 | 68k,0603 | Resistor_User:68k,0603 | Resistor_SMD:R_0603_1608Metric_Pad0.98x0.95mm_HandSolder | ~ |  |  |  |  |  | 603 | 0.1W |  |  | 68k |  |  | 1%
Ja |  |  | 29 | 1 | R113 | 47k,0603 | Resistor_User:47k,0603 | Resistor_SMD:R_0603_1608Metric_Pad0.98x0.95mm_HandSolder | ~ |  |  |  |  |  | 603 | 0.1W |  |  | 47k |  |  | 1%
 |  | Digi-Key | 30 | 1 | R114 | 50m | Resistor_User:50m,1206 | Resistor_SMD:R_1206_3216Metric_Pad1.30x1.75mm_HandSolder | ~ |  |  |  |  |  | 1206 | 1W |  |  | 50m |  |  | 0.5%
Ja |  |  | 31 | 4 | R115, R116, R119, R120 | 0R,0603 | Resistor_User:0R,0603 | Resistor_SMD:R_0603_1608Metric_Pad0.98x0.95mm_HandSolder | ~ |  |  |  |  |  | 603 | 0.1W |  |  | 0R |  |  | 1%
Ja |  |  | 32 | 1 | R118 | 49.9R,1206 | Resistor_User:49.9R,1206 | Resistor_SMD:R_1206_3216Metric_Pad1.30x1.75mm_HandSolder | ~ |  |  |  |  |  | 1206 | 0.5W |  |  | 49.9R |  |  | 1%
Ja |  | Reichelt nachbestellen? | 33 | 1 | RV101 | 10k_Potentiometer_Trim_TSR-3296W | Resistor_User:10k_Potentiometer_Trim_TSR-3296W | Potentionmeter_THT_User:Potentiometer_Suntan_3296W_Vertical_90deg | https://cdn-reichelt.de/documents/datenblatt/B400/64W100K.pdf |  |  |  | TSR-3296W | Suntan |  |  |  |  |  | 64W-10K | Reichelt
Ja |  |  | 34 | 2 | SW101, SW102 | JS202011CQN | Switch_User:Slide_Switch_JS202011CQN | Button_Switch_THT:SW_CuK_JS202011CQN_DPDT_Straight | https://www.ckswitches.com/media/1422/js.pdf |  |  |  | JS202011CQN | CuK |  |  |  |  |  | 401-2001-ND | Digi-Key
Ja |  |  | 35 | 4 | TP101, TP103, TP105, TP108 | TestPoint_5010_Red | Testpoint_User:TestPoint_5010_Red | TestPoint:TestPoint_Loop_D2.60mm_Drill1.6mm_Beaded | https://www.keystone-europe.com/wp-content/uploads/2019/11/M70_keystone_guide_2019.pdf |  | Red |  | 5010 | Keystone Electronics |  |  |  |  |  | 36-5005-ND | Digi-Key
Ja |  |  | 36 | 3 | TP102, TP104, TP107 | TestPoint_5011_Black | Testpoint_User:TestPoint_5011_Black | TestPoint:TestPoint_Loop_D2.60mm_Drill1.6mm_Beaded | https://www.keystone-europe.com/wp-content/uploads/2019/11/M70_keystone_guide_2019.pdf |  | Black |  | 5011 | Keystone Electronics |  |  |  |  |  | 36-5011-ND | Digi-Key
Ja |  |  | 37 | 1 | TP106 | TestPoint_5012_White | Testpoint_User:TestPoint_5012_White | TestPoint:TestPoint_Loop_D2.60mm_Drill1.6mm_Beaded | https://www.keystone-europe.com/wp-content/uploads/2019/11/M70_keystone_guide_2019.pdf |  | White |  | 5012 | Keystone Electronics |  |  |  |  |  | 36-5012-ND | Digi-Key
 |  | Digi-Key | 38 | 1 | U101 | MCP73832T-2ACI/OT | Battery_Management:MCP73832-2-OT | Package_TO_SOT_SMD:SOT-23-5 | http://ww1.microchip.com/downloads/en/DeviceDoc/20001984g.pdf |  |  |  |  |  |  |  |  |  |  | MCP73832T-2ACI/OTCT-ND | Digi-Key
 |  | Digi-Key | 39 | 1 | U102 | BQ29700DSER | Battery_Management:BQ297xy | Package_SON:WSON-6_1.5x1.5mm_P0.5mm | http://www.ti.com/lit/ds/symlink/bq2970.pdf
 |  | Digi-Key | 40 | 1 | U103 | TLV803EA30DBZR | Power_Supervisor_User:TLV803EA30DBZR | Package_TO_SOT_SMD:SOT-23 | https://www.ti.com/lit/ds/symlink/tlv803e.pdf |  |  |  | TLV803EA30DBZR | Texas Instruments |  |  |  |  |  | 296-TLV803EA30DBZRCT-ND | Digi-Key
 |  | Digi-Key | 41 | 1 | U104 | LM27762 | Regulator_SwitchedCapacitor:LM27762 | Package_SON:WSON-12-1EP_3x2mm_P0.5mm_EP1x2.65_ThermalVias | http://www.ti.com/lit/ds/symlink/lm27762.pdf |  |  |  |  |  |  |  |  |  |  | 296-47331-1-ND | Digi-Key
 |  | Digi-Key | 42 | 1 | U105 | AD8410AWBRZ | Amplifier_Current:AD8418 | Package_SO:SOIC-8_3.9x4.9mm_P1.27mm | https://www.analog.com/media/en/technical-documentation/data-sheets/AD8418.pdf |  |  |  |  |  |  |  |  |  |  | 505-AD8410AWBRZ-ND | Digi-Key
 |  | Digi-Key | 43 | 1 | U106 | AD8655ARZ | Amplifier_Operational:AD8655 | Package_SO:SOIC-8_3.9x4.9mm_P1.27mm | https://www.analog.com/media/en/technical-documentation/data-sheets/ad8655_8656.pdf |  |  |  |  |  |  |  |  |  |  | 505-AD8655ARZ-ND | Digi-Key

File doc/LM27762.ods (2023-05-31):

User Input
Output
OUT+ |  |  | OUT-
Vout | 3,3 | V | Vout | -2 | V
R2 | 68 | kΩ (≥ 50 kΩ) | R4 | 68 | kΩ (≥ 50 kΩ)
R1 calculated | 119,00 | kΩ | R3 calculated | 45,33 | kΩ
R1 real | 120 | kΩ | R3 real | 47 | kΩ
Vout real | 3,32 | V | Vout real | -2,03 | V

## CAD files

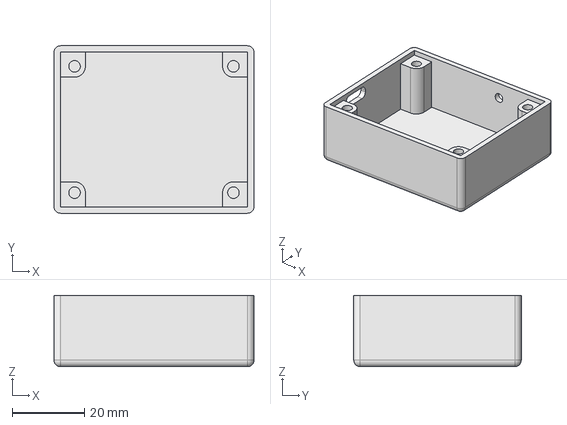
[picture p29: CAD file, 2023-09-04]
mech/SCuSA_RevB1_case.FCStd
55.4 x 46.4 x 19.8 mm

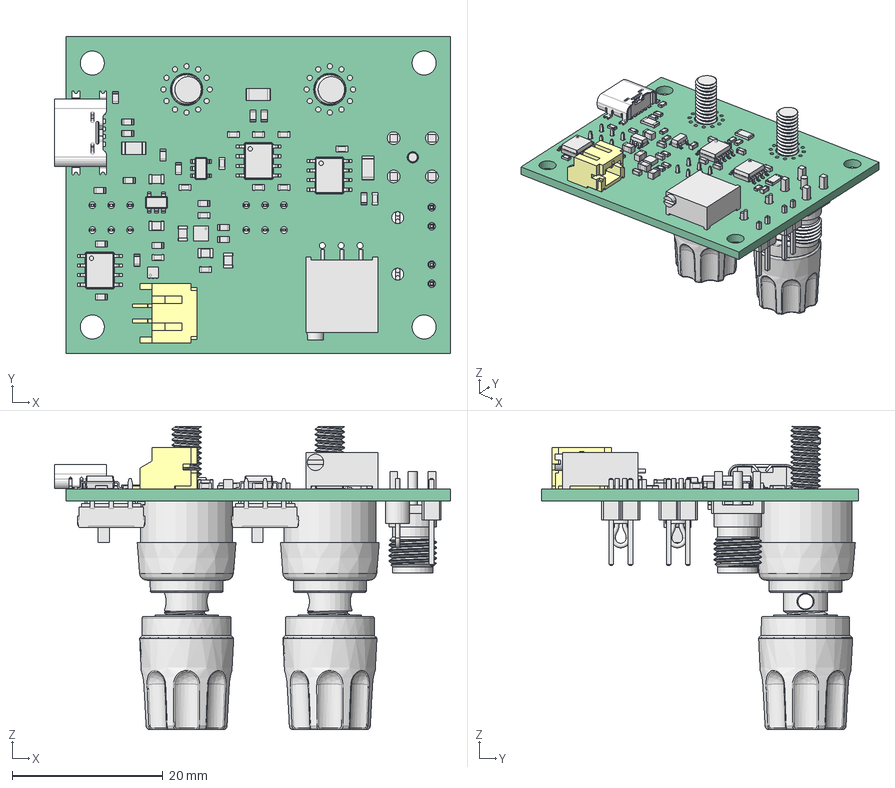
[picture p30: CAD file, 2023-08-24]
mech/SCuSA_RevB1_PCBA.FCStd
52.5 x 42.0 x 40.2 mm
Pcb_3e51
R118_R_1206_3216Metric_9a429e010c18 x 2
C110_C_0603_1608Metric_07e89f88e059 x 11
R121_R_0603_1608Metric_cabd63930a75 x 17
F101_Fuse_1206_3216Metric_160eb9ee9b08
U103_SOT_23_5_5ae0390f21ab x 2
C101_C_0805_2012Metric_832099bd49ec x 5
Q101_SOIC_8_39x49mm_P127mm_18785c1fbfb3 x 3
J102_S2B-PH-SM4_327a573b422f
USB4135-GF-A
USB4135-GF-A001
U111_WSON_8_1EP_2x2mm_P05mm_EP09x16mm_bf8e54cc5a9e
FB100_L_0603_1608Metric_5c9160750dc1
RV101_Cut_b268e7737479
U102_WSON6_15x15mm_Pitch05mm_e3a42ca1607c
J108_PinHeader_1x02_P254mm_Vertical_696c06d13264 x 2
SW101_CuK_JS202011CQN_DPDT_straight_5f730d750727 x 2
J105_60312002114503_f594866c6ba6
D102_LED_0805_2012Metric_8af6430a5faa x 3
TestPoint_Loop_D2_60mm_Drill1_6mm_Beaded_cp x 2
TestPoint_Loop_D2_60mm_Drill1_6mm_Beaded_cp001 x 2

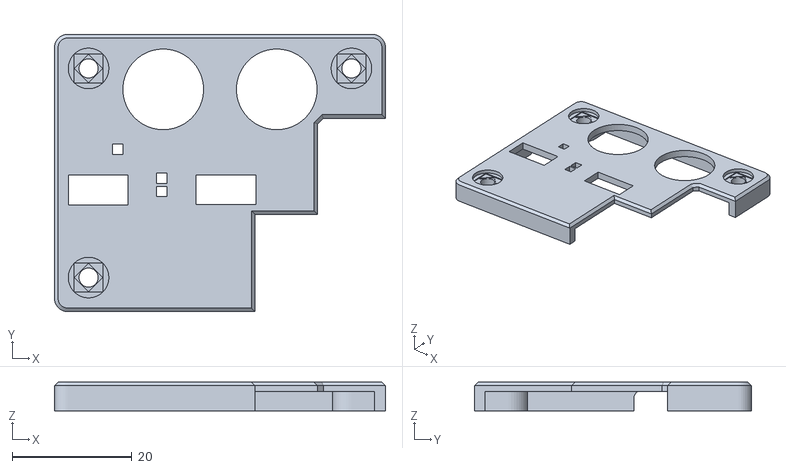
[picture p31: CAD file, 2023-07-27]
mech/SCuSA_RevA1_Lid.stl
55.4 x 46.4 x 4.80

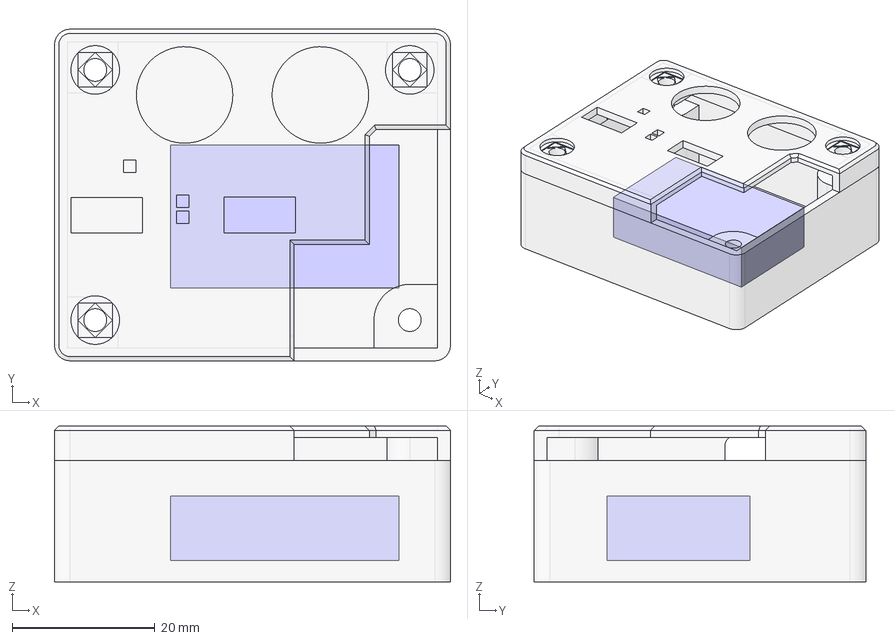
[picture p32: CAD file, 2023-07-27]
mech/SCuSA_RevA1_case.FCStd
55.4 x 46.4 x 21.8 mm
Case
LiPo_Battery
Lid

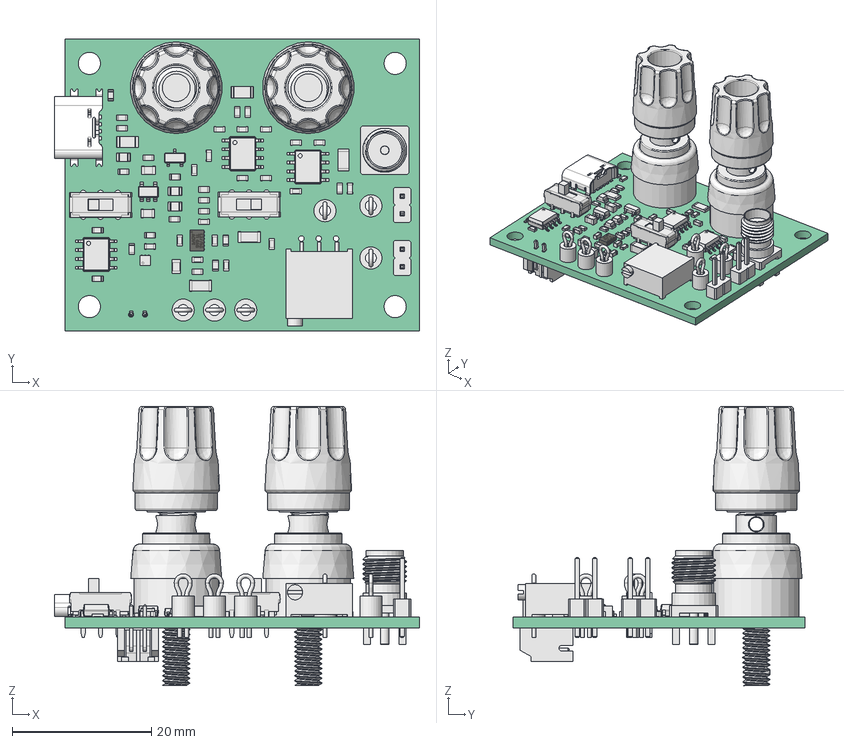
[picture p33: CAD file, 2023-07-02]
mech/SCuSA_RevA1_PCBA.FCStd
52.5 x 42.0 x 40.2 mm
Pcb_3e51
R118_R_1206_3216Metric_9a429e010c18 x 2
C110_C_0603_1608Metric_07e89f88e059 x 18
R121_R_0603_1608Metric_cabd63930a75 x 20
F101_Fuse_1206_3216Metric_160eb9ee9b08
J108_PinHeader_1x02_P254mm_Vertical_696c06d13264 x 2
C101_C_0805_2012Metric_832099bd49ec x 3
WSON-12 v7
WSON-12 v008
WSON-12 v009
WSON-12 v010
WSON-12 v011
WSON-12 v012
WSON-12 v013
WSON-12 v014
WSON-12 v015
WSON-12 v016
WSON-12 v017
WSON-12 v018
WSON-12 v019
WSON-12 v020
TestPoint_Loop_D2_60mm_Drill1_6mm_Beaded_cp x 6
TestPoint_Loop_D2_60mm_Drill1_6mm_Beaded_cp001 x 6
Q101_SOIC_8_39x49mm_P127mm_18785c1fbfb3 x 3
SW101_CuK_JS202011CQN_DPDT_straight_5f730d750727 x 2
FB101_L_1206_3216Metric_6ecc6a01b1a7 x 2
J105_60312002114503_f594866c6ba6
USB4135-GF-A
USB4135-GF-A001
D102_LED_0805_2012Metric_8af6430a5faa x 3
U103_SOT_23_415030393587
RV101_Cut_b268e7737479
U101_SOT_23_5_b81ba866f2ca
U102_WSON6_15x15mm_Pitch05mm_e3a42ca1607c
J102_JST_S2B_PH_K_64e658e90b66

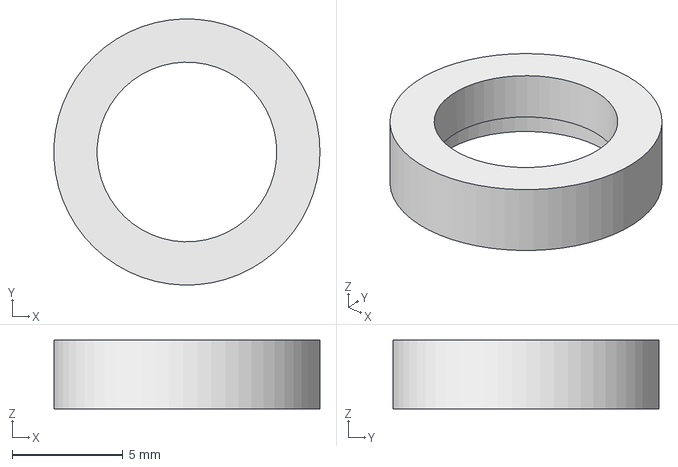
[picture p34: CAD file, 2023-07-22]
mech/nut_spacer.FCStd
12.0 x 12.0 x 3.10 mm

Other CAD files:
mech/SCuSA_RevA1_Case.3mf
mech/SCuSA_RevA1_Case.stl
mech/SCuSA_RevB1_Case.3mf
mech/nut_spacer.stl

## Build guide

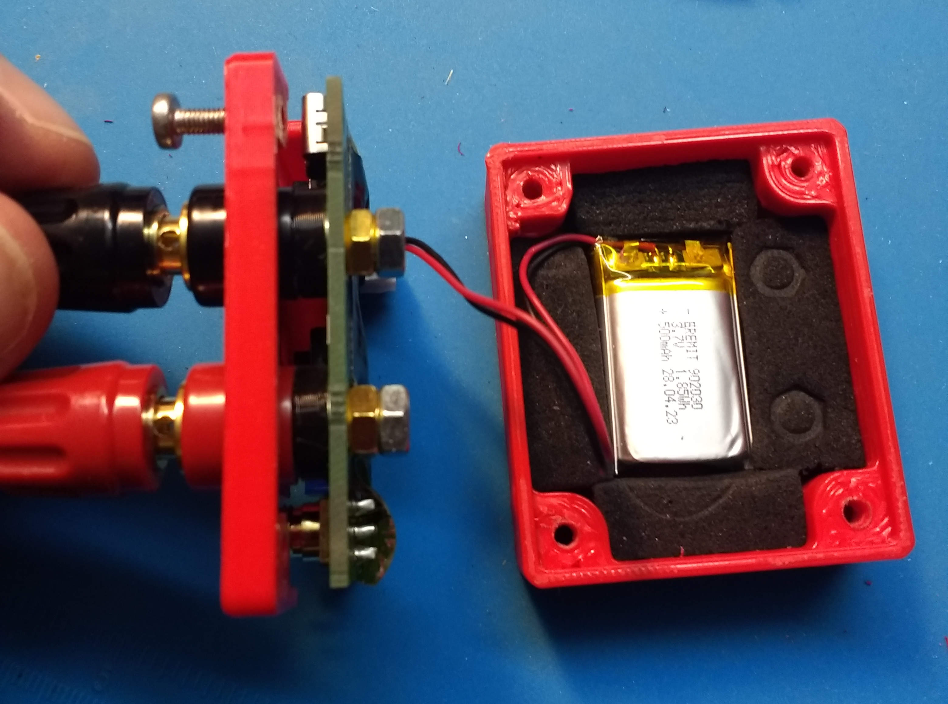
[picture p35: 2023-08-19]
doc/img/assembly00.jpg

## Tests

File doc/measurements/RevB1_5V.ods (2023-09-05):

R | +5V | Vout_U106 | Iout
9999999 | 5,009 | 5,002 | 0
139 | 4,99 | 4,813 | 0,0254
100 | 4,985 | 4,762 | 0,0216
50 | 4,972 | 4,637 | 0,045

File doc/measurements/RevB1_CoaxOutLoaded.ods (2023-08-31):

Probe_Out | Koax_Out
3,90E-03 | 3,20E-02
1,08E-01 | 2,33E-01
0,5 | 1,101
1,003 | 2,032
1,505 | 3,015
2,006 | 4,022
2,248 | 4,513
2,299 | 4,613

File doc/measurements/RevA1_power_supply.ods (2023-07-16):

Parameter | Measured value | Unit | Condition 1 | Condition 2 | Condition 3
I_VBus | 0,228 | A | Charging | VBUS = 5V
I_VBus | 0,228 | A | Charging | VBUS = 5.5V
I_VBus | 0,229 | A | Charging | VBUS = 4.5V
I_VBat | 0,01587 | A | VBat = 3.7V
I_VBat | 0,01576 | A | VBat = 3.3V
I_VBat | 0,01584 | A | VBat = 4.2V
+3V3 | 3,298 | A | VBat = 3.3V
+3V3 | 3,327 | A | VBat = 3.7V
+3V3 | 3,326 | A | VBat = 4.2V
-2V | -2,059 | A | VBat = 3.3V
-2V | -2,059 | A | VBat = 3.7V
-2V | -2,059 | A | VBat = 4.2V

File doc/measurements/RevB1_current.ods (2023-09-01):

I | Vout
0,05 | 5,05E-02
0,1 | 1,00E-01
0,9996 | 0,5004
1,996 | 1,001
3 | 1,501
4,004 | 2
5,001 | 2,498
5,8024 | 2,893
6,024 | 2,992

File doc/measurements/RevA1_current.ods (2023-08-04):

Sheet: CH1
I_set | I_meas | I_multimeter | Error | Error
0 | 0 | 0 | 0 | 0,0 %
5,00E-04 | 6,00E-04 | 1,70E-04 | 0,00043 | 252,9 %
1,00E-03 | 1,20E-03 | 6,50E-05 | 0,001135 | 1746,2 %
2,00E-03 | 2,20E-03 | 1,69E-03 | 0,00051 | 30,2 %
3,00E-03 | 3,20E-03 | 2,62E-03 | 0,00058 | 22,1 %
4,00E-03 | 4,20E-03 | 3,64E-03 | 0,00056 | 15,4 %
5,00E-03 | 5,20E-03 | 4,67E-03 | 0,00053 | 11,3 %
6,00E-03 | 6,20E-03 | 5,61E-03 | 0,000589999999999999 | 10,5 %
7,00E-03 | 7,10E-03 | 6,64E-03 | 0,00046 | 6,9 %
8,00E-03 | 8,20E-03 | 7,63E-03 | 0,000570000000000001 | 7,5 %
9,00E-03 | 9,10E-03 | 8,57E-03 | 0,000530000000000001 | 6,2 %
1,00E-02 | 1,01E-02 | 9,59E-03 | 0,00051 | 5,3 %
2,00E-02 | 2,00E-02 | 1,95E-02 | 0,000480000000000001 | 2,5 %
3,00E-02 | 2,99E-02 | 2,94E-02 | 0,000549999999999998 | 1,9 %
4,00E-02 | 3,99E-02 | 3,99E-02 | 0 | 0,0 %
5,00E-02 | 4,98E-02 | 4,93E-02 | 0,000549999999999995 | 1,1 %
6,00E-02 | 5,98E-02 | 5,93E-02 | 0,000529999999999996 | 0,9 %
7,00E-02 | 6,99E-02 | 6,90E-02 | 0,000899999999999998 | 1,3 %
0,1 | 0,1001 | 0,099 | 0,00109999999999999 | 1,1 %
0,5 | 0,4998 | 0,499 | 0,000800000000000023 | 0,2 %
1 | 0,9998 | 0,999 | 0,000800000000000023 | 0,1 %
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

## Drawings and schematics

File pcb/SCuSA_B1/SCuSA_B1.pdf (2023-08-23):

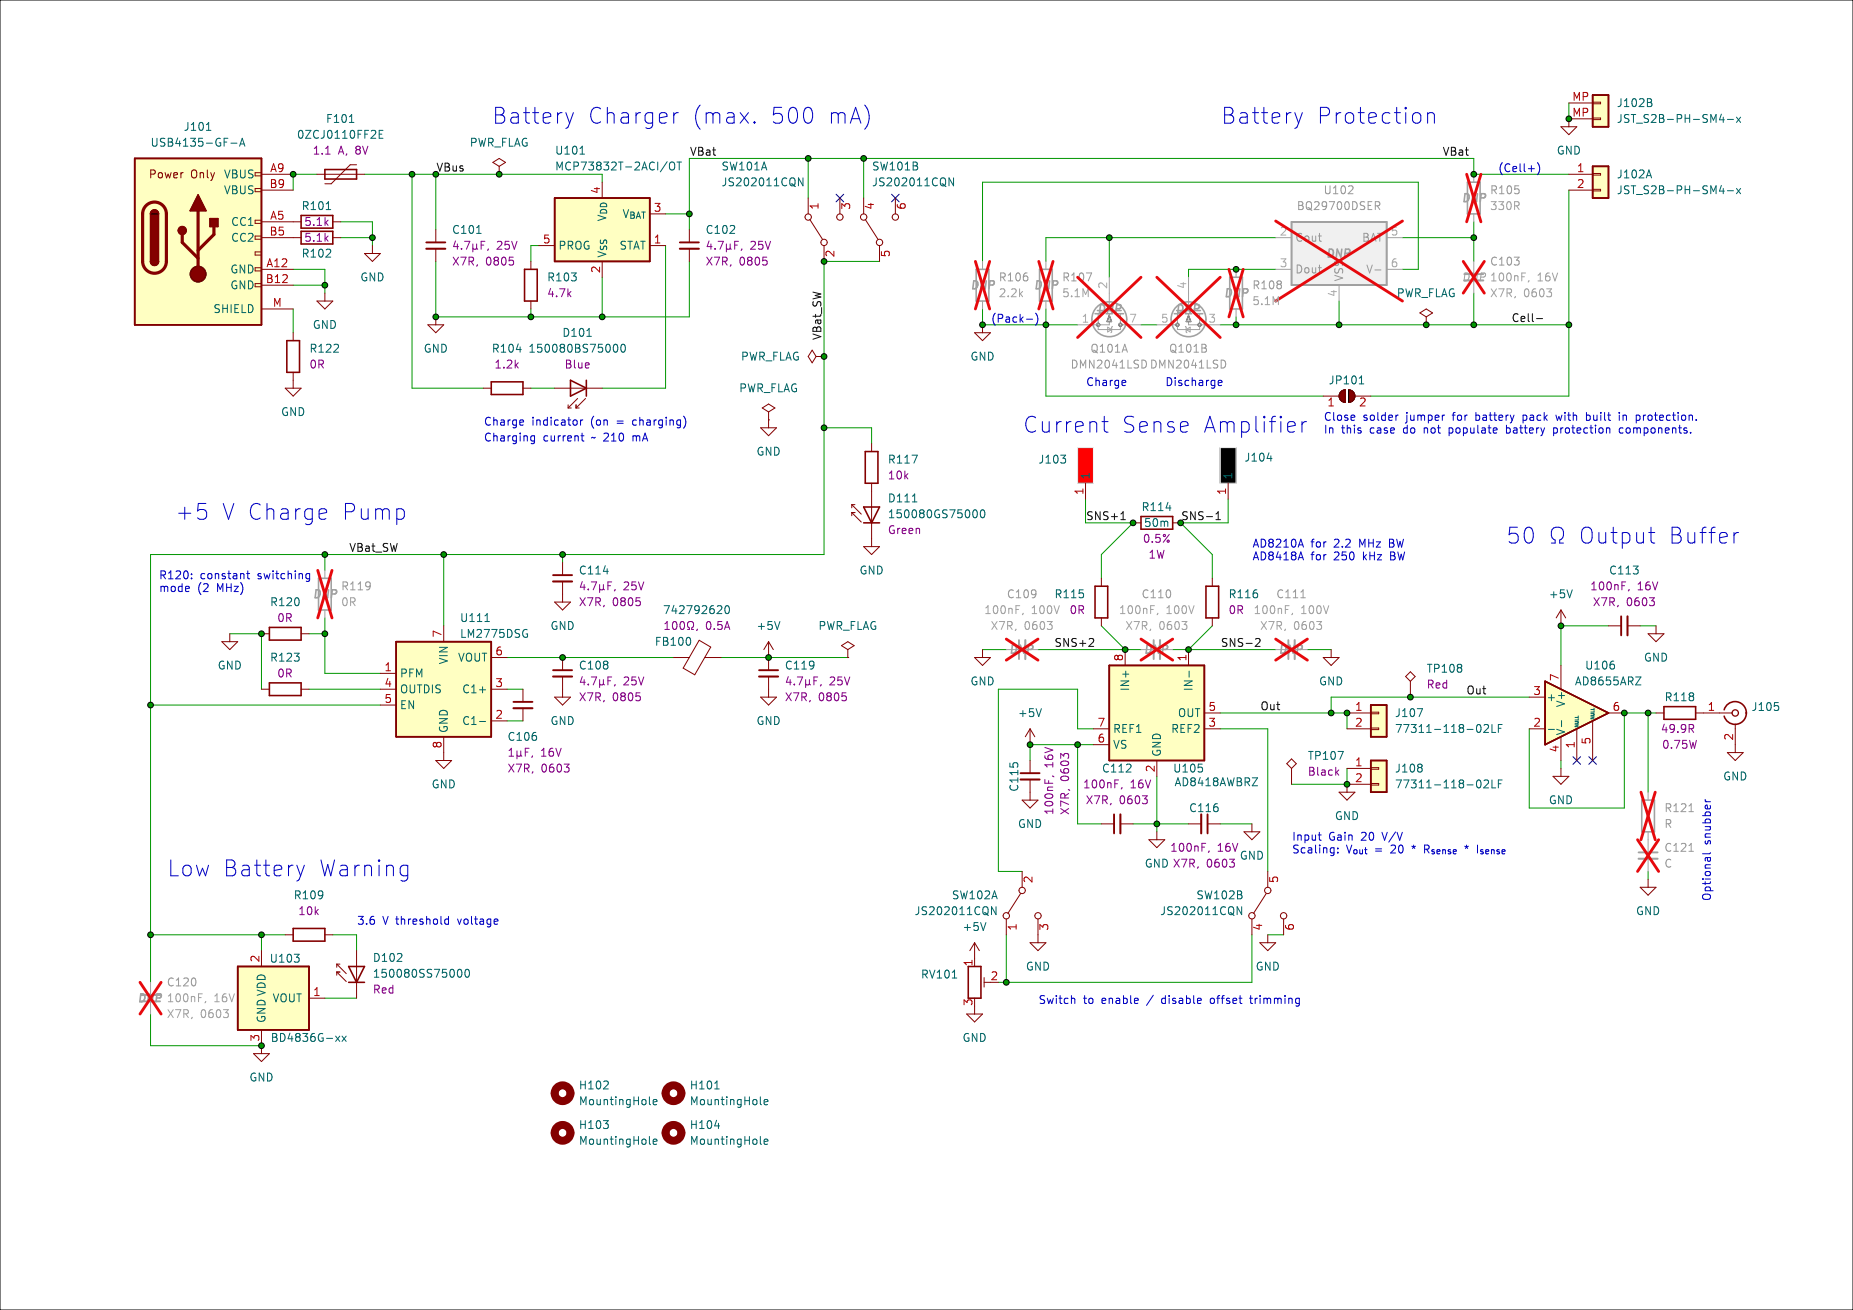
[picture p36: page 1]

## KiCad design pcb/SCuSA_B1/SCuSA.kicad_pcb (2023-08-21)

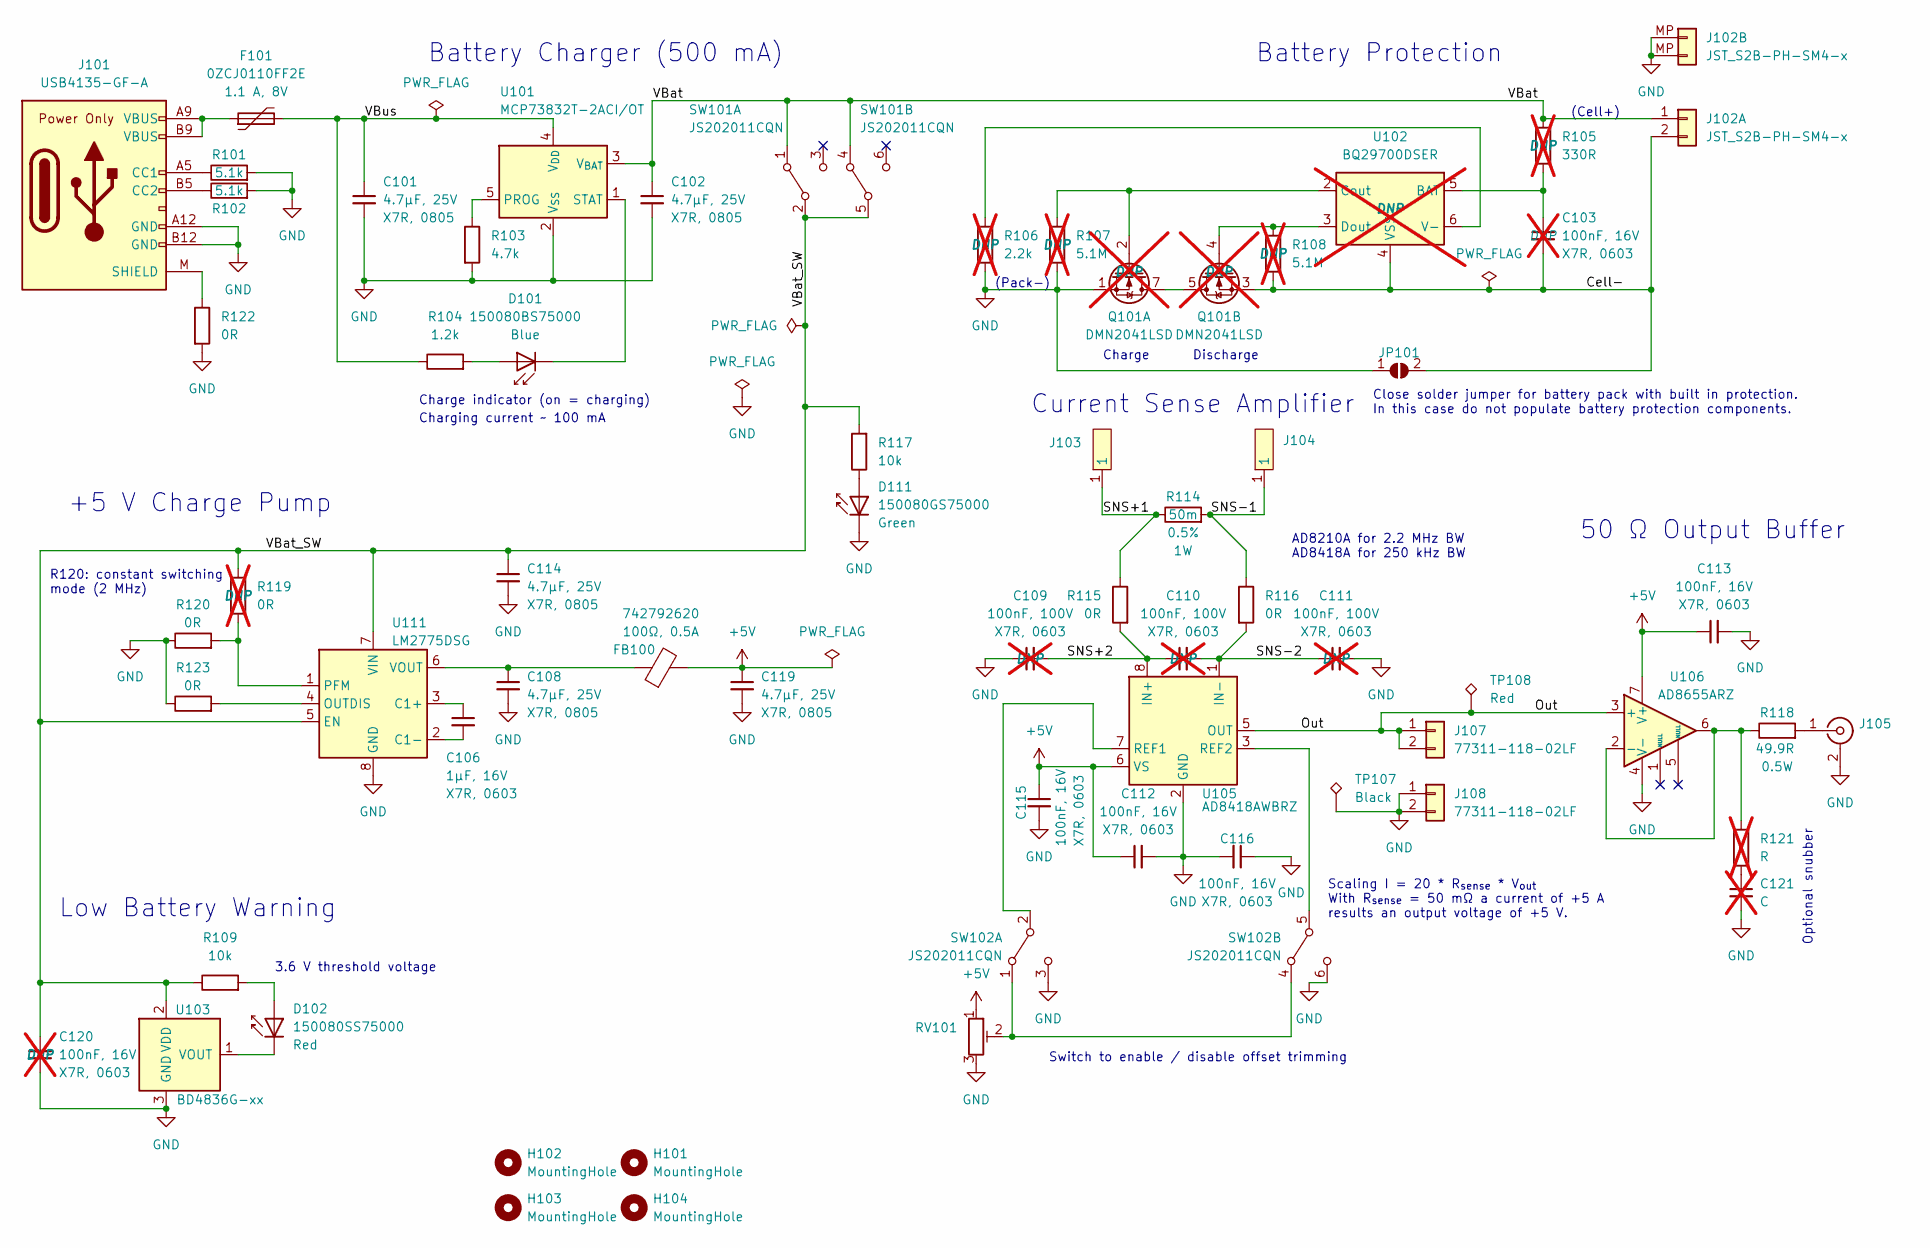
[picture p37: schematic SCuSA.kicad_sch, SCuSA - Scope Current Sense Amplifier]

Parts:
C101, C102, C108, C114, C119: 4.7uF,25V,X7R,0805; C_0805_2012Metric_Pad1.18x1.45mm_HandSolder
C103, C120: 100nF,16V,X7R,0603; C_0603_1608Metric_Pad1.08x0.95mm_HandSolder; not fitted
C106: 1uF,16V,X7R,0603; C_0603_1608Metric_Pad1.08x0.95mm_HandSolder
C109, C110, C111: 100nF,100V,X7R,0603; C_0603_1608Metric_Pad1.08x0.95mm_HandSolder; not fitted
C112, C113, C115, C116: 100nF,16V,X7R,0603; C_0603_1608Metric_Pad1.08x0.95mm_HandSolder
C121: C; C_0603_1608Metric_Pad1.08x0.95mm_HandSolder; not fitted
D101: 150080BS75000; LED_0805_2012Metric_Pad1.15x1.40mm_HandSolder
D102: 150080SS75000; LED_0805_2012Metric_Pad1.15x1.40mm_HandSolder
D111: 150080GS75000; LED_0805_2012Metric_Pad1.15x1.40mm_HandSolder
F101: 0ZCJ0110FF2E; Fuse_1206_3216Metric_Pad1.42x1.75mm_HandSolder; MPN 0ZCJ0110FF2E
FB100: 742792620; L_0603_1608Metric_Pad1.05x0.95mm_HandSolder; MPN 742792620
H101, H102, H103, H104: MountingHole; MountingHole_3.2mm_M3_DIN965
J101: USB4135-GF-A; USB-C_Receptacle_GTC_USB4135-GF-A; MPN USB4135-GF-A
J102: JST_S2B-PH-SM4-x; JST_PH_S2B-PH-SM4-TB_1x02-1MP_P2.00mm_Horizontal; MPN S2B-PH-SM4-TB
J103: Binding_Post_PKI_10_A_Au; Binding_Post_PKI_10_A_Au_Red; MPN 930103701
J104: Binding_Post_PKI_10_A_Au; Binding_Post_PKI_10_A_Au_Black; MPN 930103700
J105: SMA_Straight_Jack_Female; SMA_Vertical; MPN RF2-04A-T-00-50-G
J107, J108: 77311-118-02LF; PinHeader_1x02_P2.54mm_Vertical
JP101: SolderJumper_2_Open; SolderJumper-2_P1.3mm_Open_TrianglePad1.0x1.5mm
Q101: DMN2041LSD; SOIC-8_3.9x4.9mm_P1.27mm; MPN DMN2041LSD-13; not fitted
R101, R102: 5.1k,0603; R_0603_1608Metric_Pad0.98x0.95mm_HandSolder; Tolerance 1%
R103: 4.7k,0603; R_0603_1608Metric_Pad0.98x0.95mm_HandSolder; Tolerance 1%
R104: 1.2k,0603; R_0603_1608Metric_Pad0.98x0.95mm_HandSolder; Tolerance 1%
R105: 330R,0603; R_0603_1608Metric_Pad0.98x0.95mm_HandSolder; Tolerance 1%; not fitted
R106: 2.2k,0603; R_0603_1608Metric_Pad0.98x0.95mm_HandSolder; Tolerance 1%; not fitted
R107, R108: 5.1M,0603; R_0603_1608Metric_Pad0.98x0.95mm_HandSolder; Tolerance 1%; not fitted
R109, R117: 10k,0603; R_0603_1608Metric_Pad0.98x0.95mm_HandSolder; Tolerance 1%
R114: 50m; R_1206_3216Metric_Pad1.30x1.75mm_HandSolder; Tolerance 0.5%
R115, R116, R120, R122, R123: 0R,0603; R_0603_1608Metric_Pad0.98x0.95mm_HandSolder; Tolerance 1%
R118: 49.9R,1206; R_1206_3216Metric_Pad1.30x1.75mm_HandSolder; Tolerance 1%
R119: 0R,0603; R_0603_1608Metric_Pad0.98x0.95mm_HandSolder; Tolerance 1%; not fitted
R121: R; R_0603_1608Metric_Pad0.98x0.95mm_HandSolder; not fitted
RV101: 10k_Potentiometer_Trim_TSR-3296W; Potentiometer_Suntan_3296W_Vertical_90deg; MPN TSR-3296W
SW101, SW102: JS202011CQN; SW_CuK_JS202011CQN_DPDT_Straight; MPN JS202011CQN
TP107: TestPoint_5011_Black; TestPoint_Loop_D2.60mm_Drill1.6mm_Beaded; MPN 5011
TP108: TestPoint_5010_Red; TestPoint_Loop_D2.60mm_Drill1.6mm_Beaded; MPN 5010
U101: MCP73832T-2ACI/OT; SOT-23-5
U102: BQ29700DSER; WSON-6_1.5x1.5mm_P0.5mm; not fitted
U103: BD4836G-xx; SOT-23-5; MPN BD4836G-xx
U105: AD8418AWBRZ; SOIC-8_3.9x4.9mm_P1.27mm; MPN AD8418AWBRZ
U106: AD8655ARZ; SOIC-8_3.9x4.9mm_P1.27mm
U111: LM2775DSG; WSON-8-1EP_2x2mm_P0.5mm_EP0.9x1.6mm_ThermalVias

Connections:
+5V: C112.1, C113.1, C115.1, C119.1, FB100.2, RV101.1, U105.6 (VS), U106.7 (V+)
/Cell-: C103.2, J102.2, JP101.2 (B), Q101.3 (S2), R108.2, U102.4 (VSS)
/Out: J107.1, J107.2, TP108.1, U105.5 (OUT), U106.3 (+)
/SNS+1: J103.1, R114.1, R115.1
/SNS+2: C109.2, C110.1, R115.2, U105.8 (IN+)
/SNS-1: J104.1, R114.2, R116.1
/SNS-2: C110.2, C111.1, R116.2, U105.1 (IN-)
/VBat: C102.1, J102.1, R105.1, SW101.1 (A), SW101.4 (A), U101.3 (V_{BAT})
/VBat_SW: C114.1, C120.2, R109.1, R117.2, R119.1, SW101.2 (B), SW101.5 (B), U103.2 (VDD), U111.5 (EN), U111.7 (VIN)
/VBus: C101.1, F101.2, R104.1, U101.4 (V_{DD})
GND: C101.2, C102.2, C108.2, C109.1, C111.2, C112.2, C113.2, C114.2, C115.2, C116.1, C116.2, C119.2, C120.1, C121.2, D111.1 (K), J101.A12 (GND), J101.B12 (GND), J102.MP, J105.2 (Ext), J108.1, J108.2, JP101.1 (A), Q101.1 (S1), R101.2, R102.2, R103.2, R106.2, R107.2, R120.1, R122.2, R123.1, RV101.3, SW102.3 (C), SW102.6 (C), TP107.1, U101.2 (V_{SS}), U103.3 (GND), U105.2 (GND), U106.4 (V-), U111.8 (GND), U111.9 (GND)
unnamed: C121.1, R121.2
unnamed: D101.2 (A), R104.2
unnamed: D101.1 (K), U101.1 (STAT)
unnamed: D102.2 (A), R109.2
unnamed: D102.1 (K), U103.1 (VOUT)
unnamed: D111.2 (A), R117.1
unnamed: F101.1, J101.A9 (VBUS), J101.B9 (VBUS)
unnamed: J101.A5 (CC1), R101.1
unnamed: J101.B5 (CC2), R102.1
unnamed: J101.M (SHIELD), R122.1
unnamed: J105.1 (In), R118.2
unnamed: Q101.5 (D2), Q101.6 (D2), Q101.7 (D1), Q101.8 (D1)
unnamed: Q101.2 (G1), R107.1, U102.2 (Cout)
unnamed: Q101.4 (G2), R108.1, U102.3 (Dout)
unnamed: RV101.2, SW102.1 (A), SW102.4 (A)
unnamed: SW102.2 (B), U105.7 (REF1)
unnamed: SW102.5 (B), U105.3 (REF2)
unnamed: R103.1, U101.5 (PROG)
unnamed: C103.1, R105.2, U102.5 (BAT)
unnamed: R106.1, U102.6 (V-)
unnamed: R118.1, R121.1, U106.2 (-), U106.6
unnamed: C106.1, U111.3 (C1+)
unnamed: C106.2, U111.2 (C1-)
unnamed: R123.2, U111.4 (OUTDIS)
unnamed: R119.2, R120.2, U111.1 (PFM)
unnamed: C108.1, FB100.1, U111.6 (VOUT)

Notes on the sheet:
+5 V Charge Pump
Charge
Battery Protection
Charging current ~ 100 mA
Optional snubber
Switch to enable / disable offset trimming
3.6 V threshold voltage
Current Sense Amplifier
(Pack-)
Discharge
(Cell+)
Close solder jumper for battery pack with built in protection. In this case do not populate battery protection components.
Battery Charger (500 mA)
Low Battery Warning
Scaling I = 20 * R_{sense} * V_{out} With R_{sense} = 50 mΩ a current of +5 A results an output voltage of +5 V.
Charge indicator (on = charging)
R120: constant switching mode (2 MHz)
AD8210A for 2.2 MHz BW AD8418A for 250 kHz BW
50 Ω Output Buffer

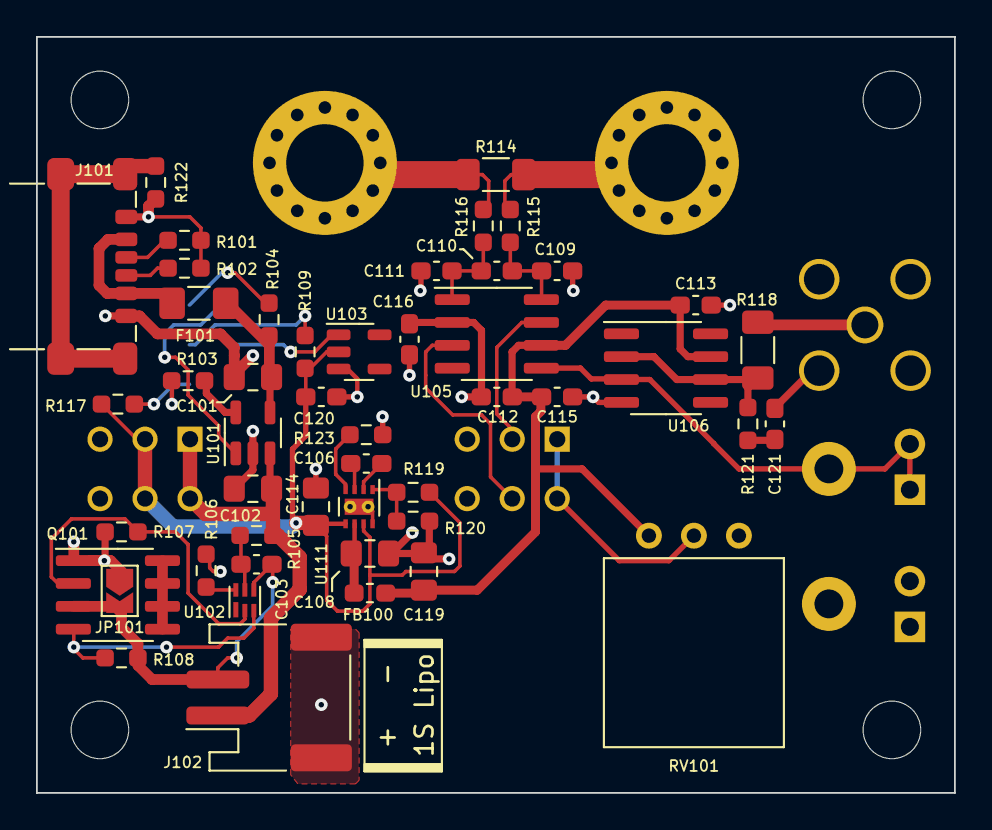
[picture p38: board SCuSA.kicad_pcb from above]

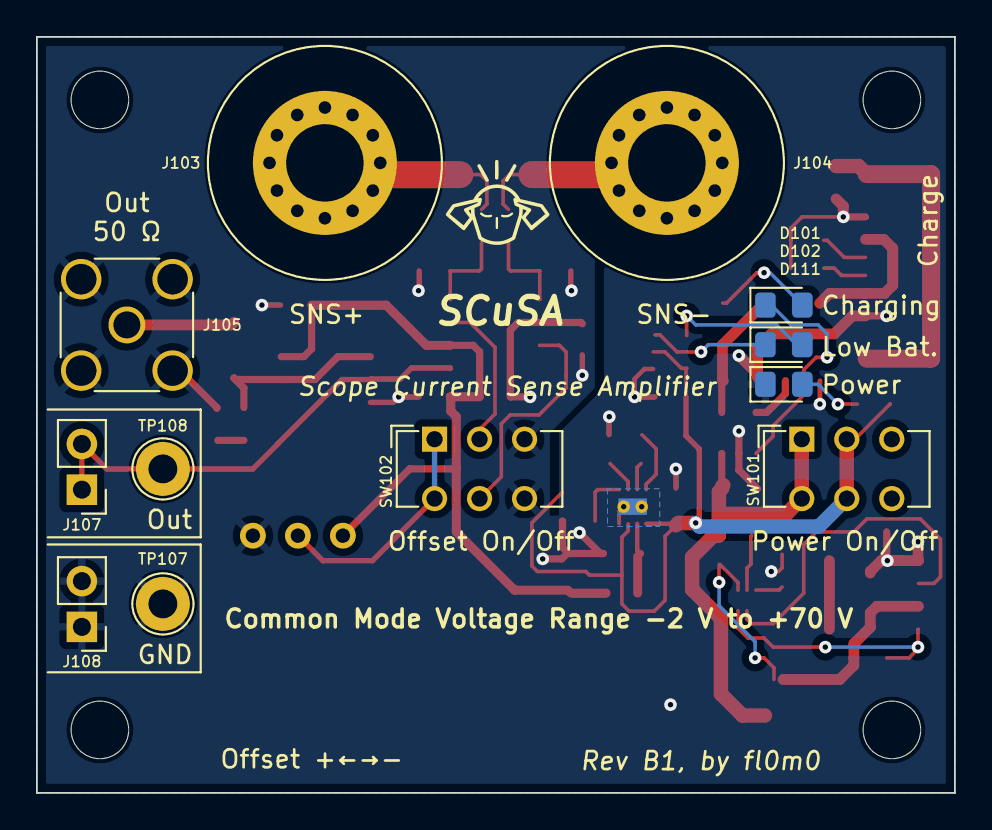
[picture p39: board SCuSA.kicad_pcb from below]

Board: 2 copper layers, 51.0 x 42.0 mm, 64 parts (12 on the bottom side), 37 nets.

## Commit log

2023-05-30 Create KiCad project
    [SCuSA.kicad_pcb, SCuSA.kicad_sch]
2023-05-31 Add alternative part simulation
    [SCuSA.kicad_sch]
2023-05-31 Switch to LM27762
    [SCuSA.kicad_sch]
2023-05-31 Add power supply
    [LM27762.ods, SCuSA.kicad_sch]
2023-06-01 Add battery circuit
    [BQ297xx.ods, SCuSA.kicad_pcb, SCuSA.kicad_sch]
2023-06-01 Work on battery charger
    [BQ297xx.ods, SCuSA.kicad_pcb, SCuSA.kicad_sch]
2023-06-02 Change battery charger
    [SCuSA.kicad_sch]
2023-06-02 Add trimpot, bindingpost
    [SCuSA.kicad_pcb, SCuSA.kicad_sch]
2023-06-03 Completion of schematic (for now)
    [SCuSA.kicad_pcb, SCuSA.kicad_sch]
2023-06-04 Add connectors, supply voltage filter
    [SCuSA.kicad_pcb, SCuSA.kicad_sch]
2023-06-04 Preliminary BOM
    [SCuSA.csv, SCuSA.kicad_pcb, SCuSA.kicad_sch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]
2023-06-06 Work on PCB layout
    [SCuSA.kicad_pcb, SCuSA.kicad_sch]
2023-06-08 Edit PCB layout
    [SCuSA.kicad_pcb, SCuSA.kicad_sch]
2023-06-18 Change binding posts and GND planes
    [SCuSA.kicad_pcb, SCuSA.kicad_sch]
2023-07-01 Fix errors, edit PCB layout
    [SCuSA.kicad_pcb, SCuSA.kicad_sch]
2023-07-02 Minor SCH and PCB modifications
    [SCuSA.kicad_pcb, SCuSA.kicad_sch]
2023-07-02 Add ibom, Aisler project ID
    [SCuSA.kicad_pcb]
2023-07-15 Add new revision B1
    [SCuSA.kicad_pcb, SCuSA.kicad_sch]
2023-07-16 Increase charge current, change LED resistors
    [RevA1_measurements.ods, SCuSA.kicad_pcb, SCuSA.kicad_sch]
2023-07-22 Finalize case, change binding post pad
    [SCuSA.kicad_pcb, SCuSA_RevA1_Case.3mf, SCuSA_RevA1_Case.stl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]
2023-07-23 Increase case dimensions
    [SCuSA_RevA1_Case.3mf, SCuSA_RevA1_Case.stl, SCuSA_RevA1_case.FCStd]
2023-07-23 Add lid to case
    [SCuSA_RevA1_Lid.stl, SCuSA_RevA1_case.FCStd]
2023-07-27 Modify lid case
    USB cutout, countersunk
    [SCuSA_RevA1_Lid.stl, SCuSA_RevA1_case.FCStd]
2023-08-04 Add measurements
    [GPP-4323.ods, SDS2504XPlus_Bode_1.csv]
2023-08-04 Edit documentation
    [GPP-4323.ods, SDS2504XPlus_Bode_1.csv, current.ods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]
2023-08-06 Fix TLV803EA30DBZR (non-R pinout)
    [SCuSA.kicad_pcb, SCuSA.kicad_sch]
2023-08-19 Change charge pump
    [SCuSA.kicad_pcb, SCuSA.kicad_sch]
2023-08-19 Change voltage supervisor
    [SCuSA.kicad_pcb, SCuSA.kicad_sch]
2023-08-21 PCB RevB1
    [SCuSA.kicad_pcb, SCuSA.kicad_sch, SCuSA_RevB1_PCBA.FCStd]
2023-08-23 BOM modifications
    [SCuSA.kicad_sch]
2023-08-24 Add case for RevB1
    [SCuSA_RevB1_PCBA.FCStd, SCuSA_RevB1_case.FCStd]
2023-08-31 Create documentation for RevB1
    [RevB1_CoaxOutLoaded.ods]
2023-09-01 Update documentation
    [RevA1_current.ods, RevA1_power_supply.ods, RevB1_current.ods]
2023-09-04 Update documentation, add Cura project
    [SCuSA_RevB1_Case.3mf, SCuSA_RevB1_case.FCStd]
